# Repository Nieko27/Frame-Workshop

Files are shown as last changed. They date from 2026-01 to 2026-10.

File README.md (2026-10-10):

## Note
A forewarning, I am very new to electronics design in general. I apologize in advance for any really baffling design decisions. I hope to learn from these projects and will keep them updated as I learn more. Thank you for your patience.

> ⚠️This is an unofficial 3rd-party project with no association to Valve.
<p align="center">
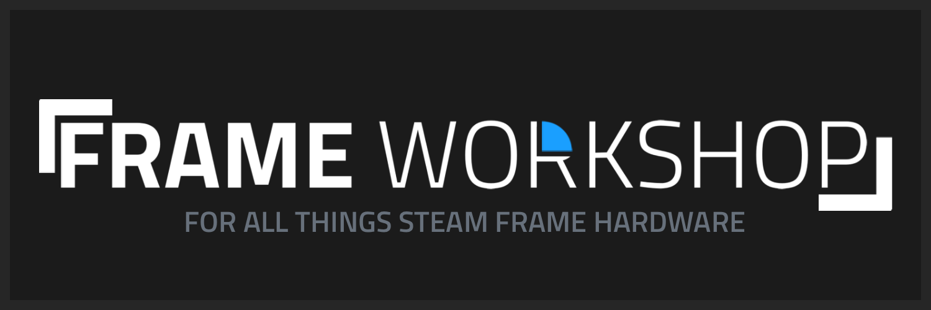
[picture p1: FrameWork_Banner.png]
Banner
  
</p>

## Offical CAD and Electronic files from Valve
If you are looking for Valves offical CAD and electronic information for the Frame it can be found here;
https://gitlab.steamos.cloud/SteamHardware/SteamFrame/-/tree/master

# What is Frame Workshop?
Frame Workshop is intended to be an open-source bundle of different hardware peripherals built around (but not always exclusive to) the Steam Frame. The idea is to leverage the Steam Frames' modularity and general openness to create a collection of open-source hardware projects that the community can provide feedback on, expand upon, or even take and turn into something entirely new, creating a feedback loop that adds to an ever-expanding ecosystem for the Steam Frame. All source files, from schematics to STLs, will be included, allowing every aspect of each project to be modified and produced to anyone’s preferences. 

## Hardware
Below is a list of all currently in development hardware projects, including a brief overview and notes on changes made to the most recent revision.

### Frame Facetracker
The Frame face tracker is pretty self-explanatory: it is a module that uses a camera for face tracking in social experiences like VRChat. There are 2 versions planned: one built with the steam frame in mind, using its expansion ports, and another that plugs into the back USB port of the frame and uses an ESP32 to run the camera.

<p align="left">
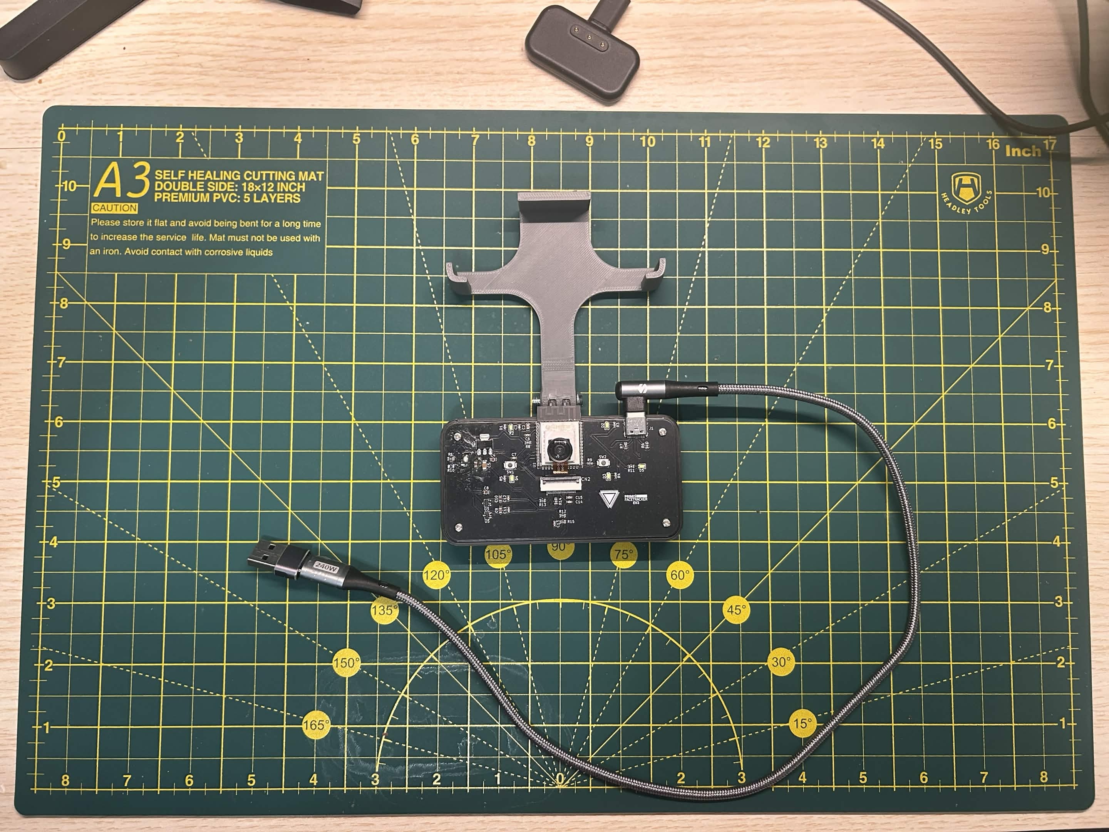
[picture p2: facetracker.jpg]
  
</p>

>Headset-Agnostic Version EV2

<br>
Link to the facetracker files:
https://github.com/Nieko27/FrameWork/tree/main/KICAD%20Projects/Primis_FaceTracker

### Versipellis (General Purpose Dongle)
Versipellis is a dongle utilising an nRF52833 intended as a general-purpose dongle for communicating with any Frame-based hardware, whether it be controllers or trackers. It will be programmable by the end user for whatever they intend to use it for. There will be two versions: one utilising no parts smaller than a 0603 package, making it easy to hand-assemble, and another using much smaller parts that, while smaller, will require assembly by a service like JLCPCB.

<p align="left">
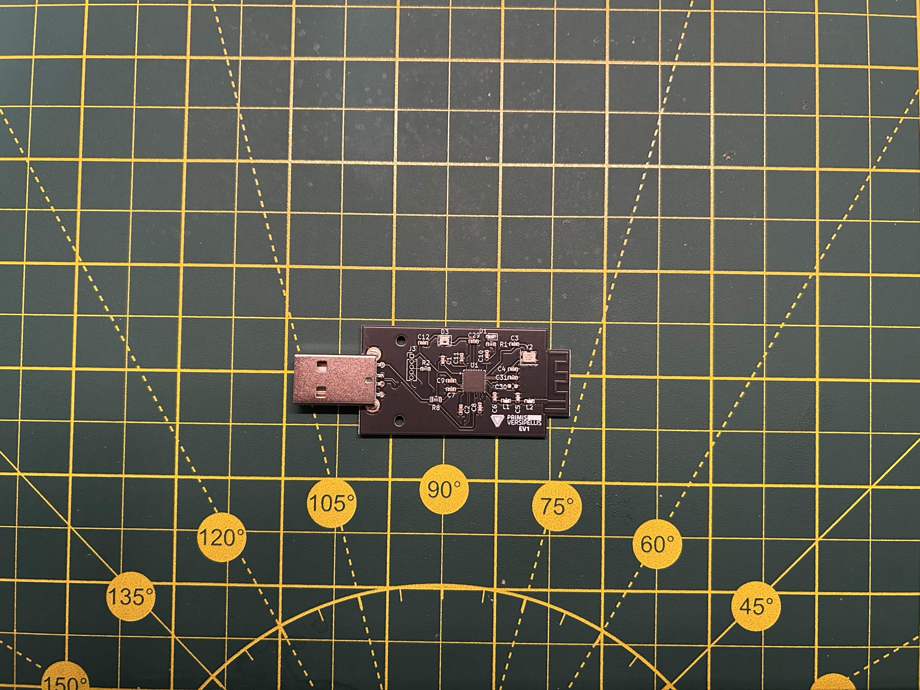
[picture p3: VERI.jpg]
  
</p>

>Hand-assemblable EV1

<br>
Link to Versipellis' files:
https://github.com/Nieko27/FrameWork/tree/main/KICAD%20Projects/Primis_Versipellis
<br>
Link to VeriMini files:
https://github.com/Nieko27/FrameWork/tree/main/KICAD%20Projects/Primis_Versipellis

### Locus (Tracker)
Locus is intended to be a tracker like Vive or Tundra, but without reliance on lighthouse base stations. Since the Steam Frame isn’t limited to base station vision, trackers being used with it shouldn’t be either. Similar to Versipellis, Locus will also use an nRF52833 along with an LSM6DSV16X IMU. The idea is that it will track similarly to a slime tracker, but also use the Steam Frame’s optical tracking to address the drift problem of EMF trackers. 

<p align="left">
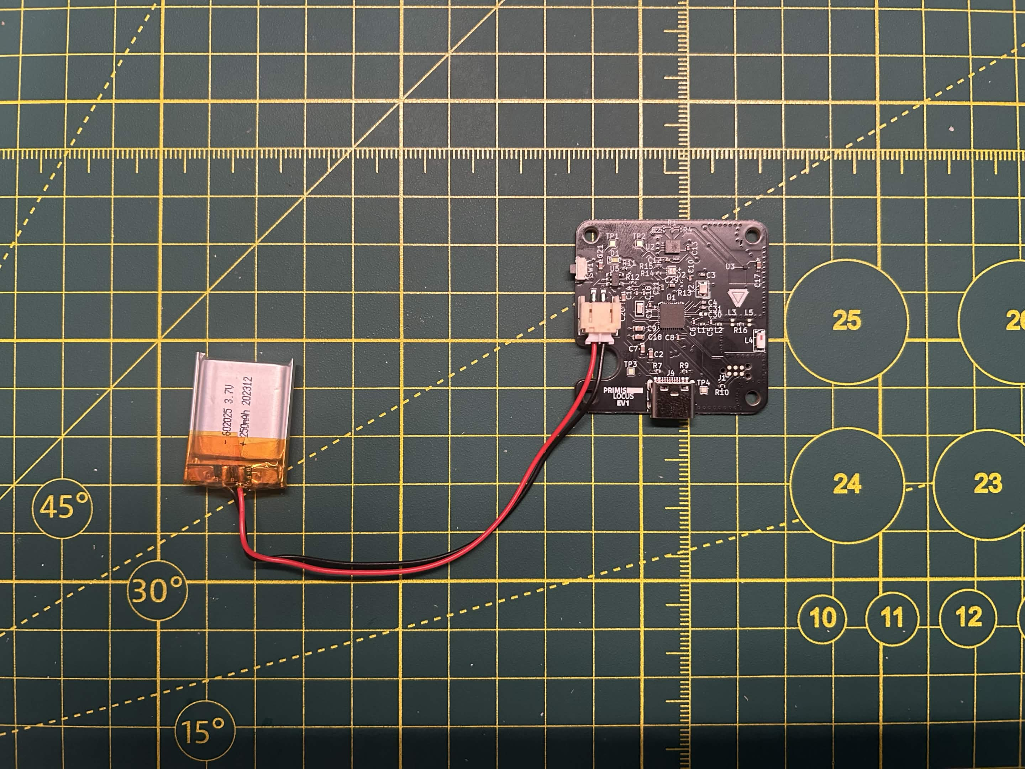
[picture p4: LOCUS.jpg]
  
</p>

Link to Locus' files:
https://github.com/Nieko27/FrameWork/tree/main/KICAD%20Projects/Primis_Locus

### Future Projects
* USB Hub
* Index speaker mod kit

## Project Goals

* Keep costs to the users as low as possible. You've already spent over a $1000 on the headset itself, so it would be nice not to have to spend another $1000 customizing it to your liking. How this would be achieved is by everything being open and nothing being sold, for example I’m working on a face tracker that takes advantage of the PCIe port on the Frame, the idea is when its done instead of me having to handle production, shipping and all the joys of selling a project I give the source files out with a tutorial on how to order it yourself from a company like JLCPCB. Now, obviously, this still won't be free to the end user, but it will be much cheaper than if I were to sell it. For example, I have made the first prototype of the face-tracker, and in small quantities (5 to be exact), it cost me $25 per board. Compare that to something like the old Vive face trackers, which I think were closer to $100, and you save a nice bit of money. 

* Give the end user total control over the hardware. Don't like how I've done something? Fire up Blender or KiCad and change it yourself to fit whatever need you have in mind. I know not everyone will be able to do this, as it requires familiarity with the software, but it gives people the ability to do so. Obviously, with this in mind, I want to make the experience for everyone as smooth as possible out of the box, so I will be listening to feedback as much as possible to achieve that. 

* Create a feedback loop. I have all this under a CERN-OHL-S-2.0 license, which (as far as I understand) means you can do anything you want with anything in the repo, including selling it for profit, but you must open-source anything you do under the same license. This way it keeps everything open to the community, and every addition helps grow the ecosystem around the Steam Frame. 

## Ideas
A few ideas for possible mods for the Frame have already been thrown around. If you have an idea for a mod, whether it's a full module or as simple as a 3D-printable counterweight, feel free to open a pull request under the enhancement tag. You may also feel free to email me at nieko972@gmail.com.

### Find me on
* Twitter; https://x.com/Merlinr271
* Bluesky; https://bsky.app/profile/merlin271.bsky.social

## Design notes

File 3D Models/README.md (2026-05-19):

Parts for the PCBs that can be 3D printed

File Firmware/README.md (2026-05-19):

## Note
This folder will hold the firmware for each device and a guide on how to set it up.

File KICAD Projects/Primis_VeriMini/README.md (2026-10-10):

### WARNING
This has yet to be produced by me yet, I have not yet added the gerber files to this repo yet as I have no idea if it will work yet, order them at your own risk.
# VERI-MINI
The general purpose dongle for the Steam Frame but smaller.
<p align="left">
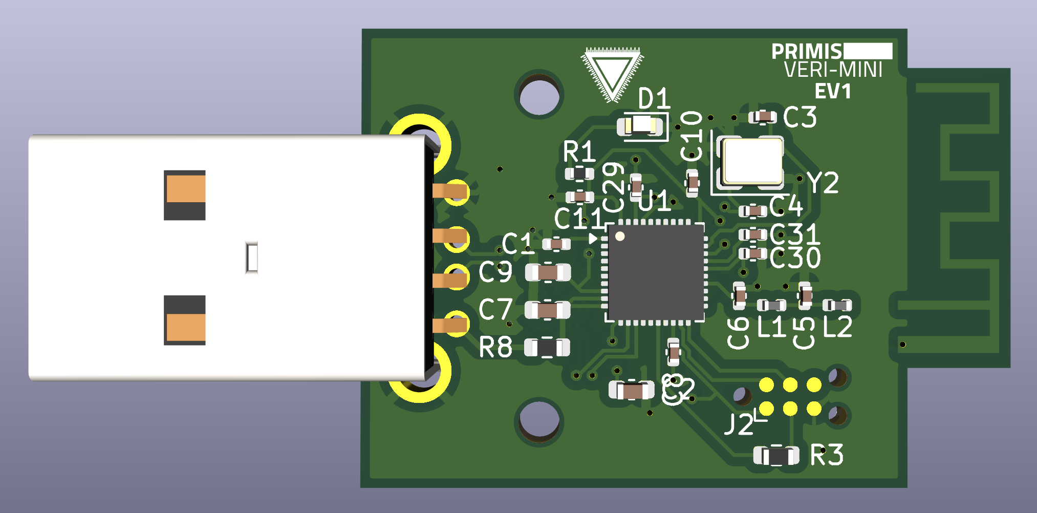
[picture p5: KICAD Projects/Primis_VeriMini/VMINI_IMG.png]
  
</p>

### Schematics
<p align="left">
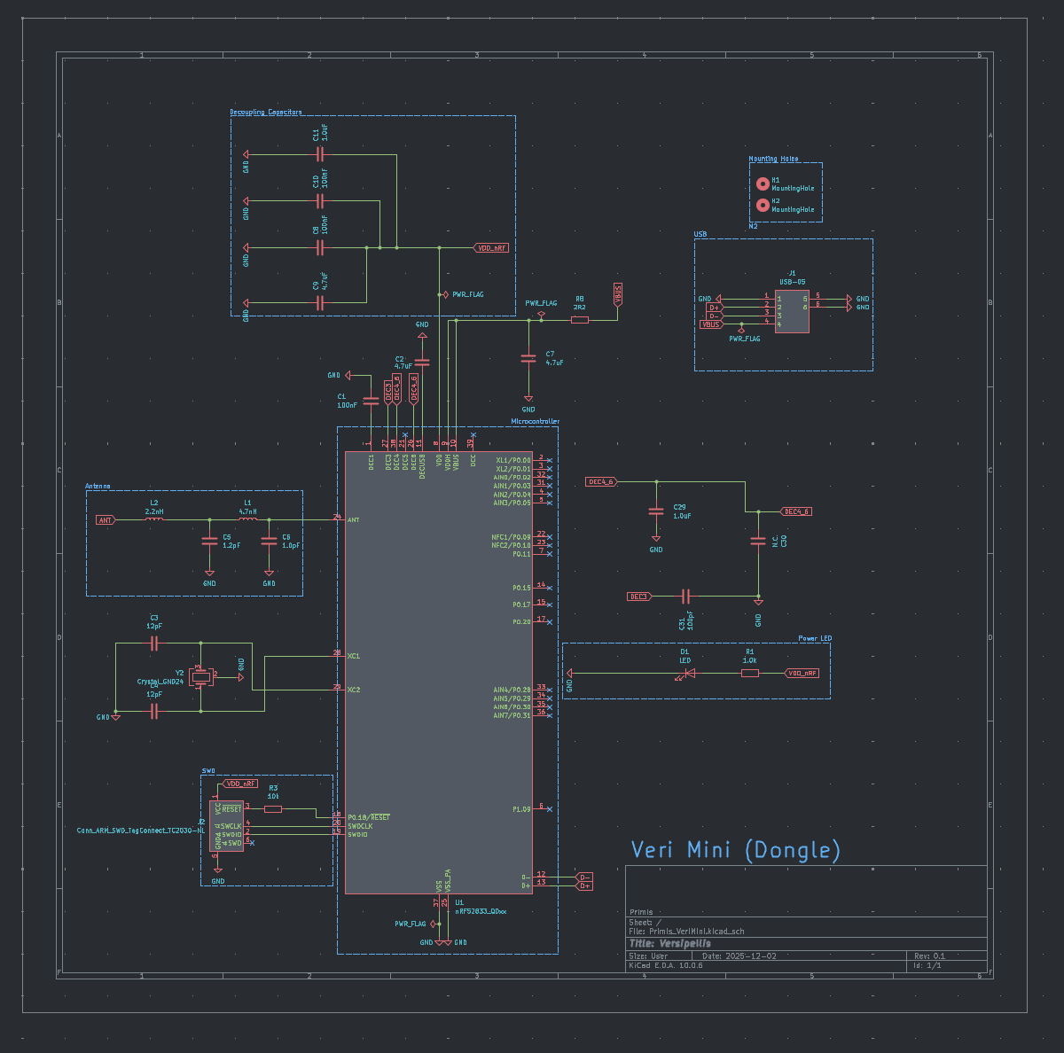
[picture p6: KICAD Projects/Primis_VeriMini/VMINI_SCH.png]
  
</p>

### PCB
<p align="left">
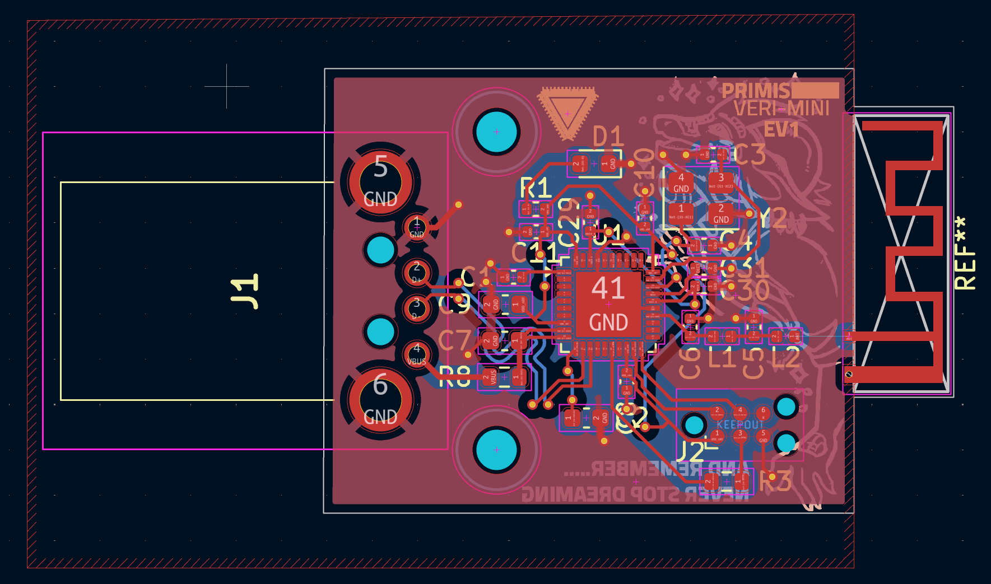
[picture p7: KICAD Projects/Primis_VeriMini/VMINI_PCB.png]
  
</p>

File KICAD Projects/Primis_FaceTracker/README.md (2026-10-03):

### WARNING
This has yet to be produced by me yet, I have not yet added the gerber files to this repo yet as I have no idea if it will work yet, order them at your own risk.
### TODO
* Copper pads under power supply
* Clean up and condense
* ESD Protection
# Face Tracker (Headset-Agnostic Version)
Headset-agnostic face tracker. Can be used with Frame by using the USB-C port on the battery.
## Current Isseus
Q1 is setup improperly, removing it and R10 as well as bridging the now empty pads solves the issue. Will fix in EV3 along with some changes to layout and LEDs.
<p align="left">
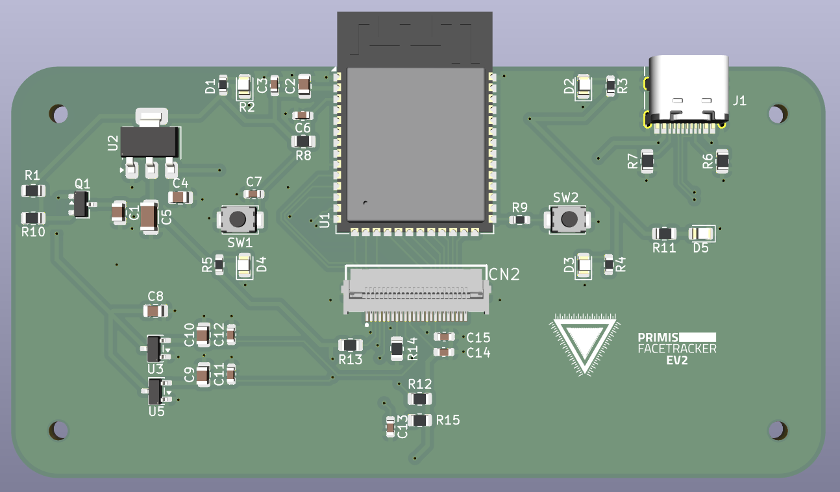
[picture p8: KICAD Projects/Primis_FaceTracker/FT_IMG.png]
  
</p>

### Schematics
<p align="left">
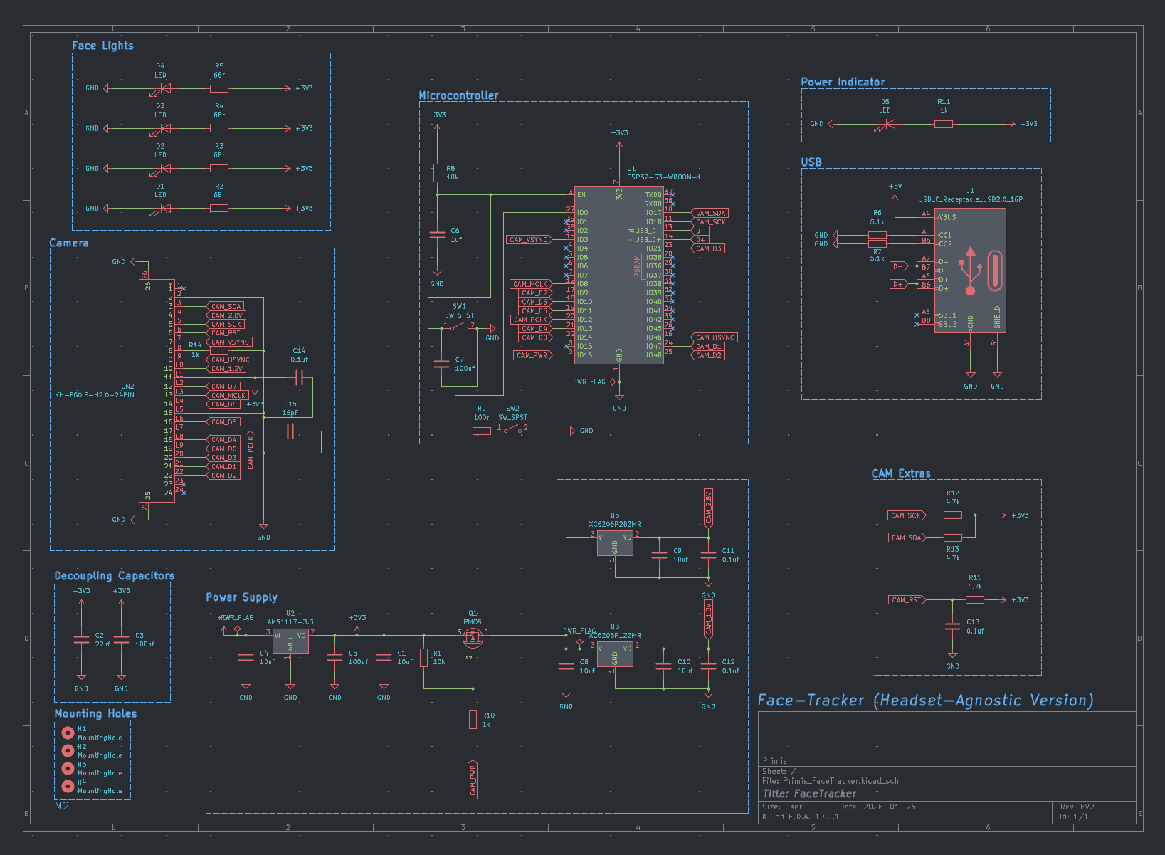
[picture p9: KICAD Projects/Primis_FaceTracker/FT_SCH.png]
  
</p>

### PCB
<p align="left">
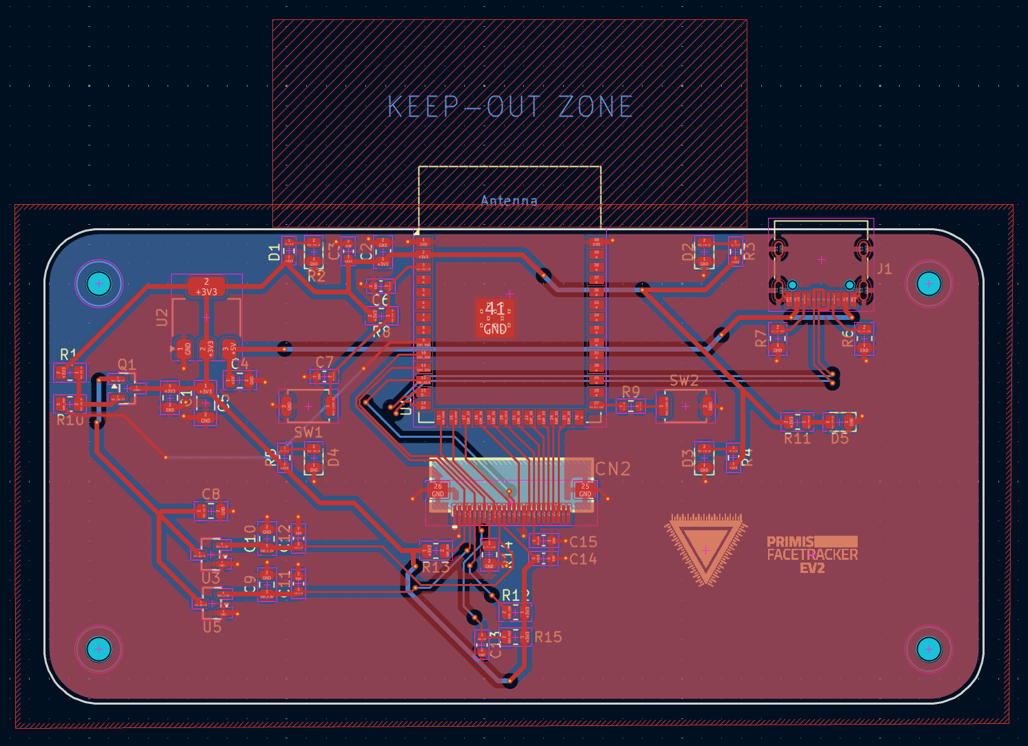
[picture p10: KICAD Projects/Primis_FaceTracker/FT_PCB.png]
  
</p>

### EV2
<p align="left">
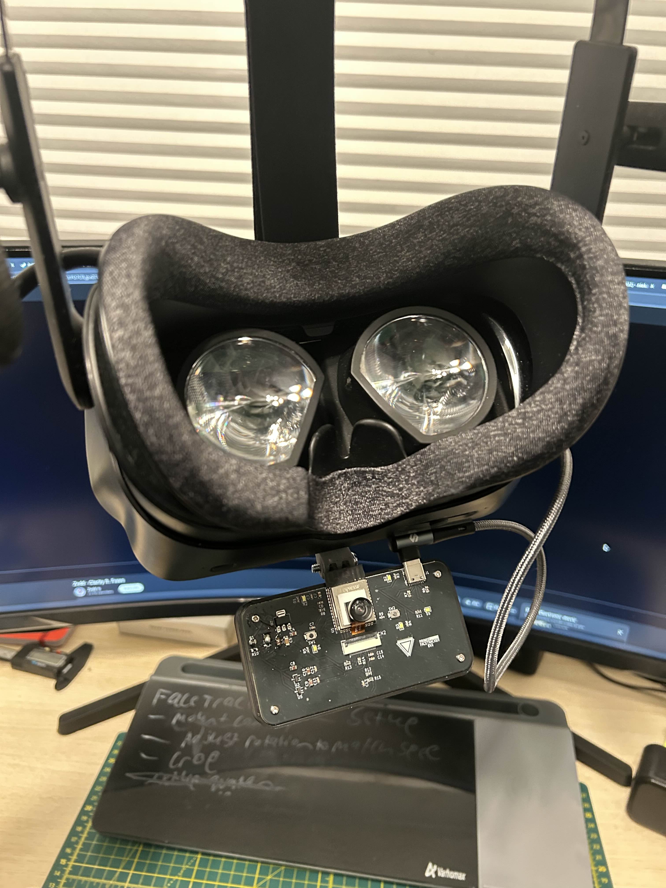
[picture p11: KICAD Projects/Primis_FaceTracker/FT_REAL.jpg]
  
</p>

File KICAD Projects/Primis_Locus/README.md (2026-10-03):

# Locus
Tracker for the Steam Frame.
## Current Isseus
Currently the SDA line is getting pulled 0.02v while running the slime firmware, if I halt the NRF52833 it jumps up to the expected 1.8v. Currently working on figuring out why this happens.
<p align="left">
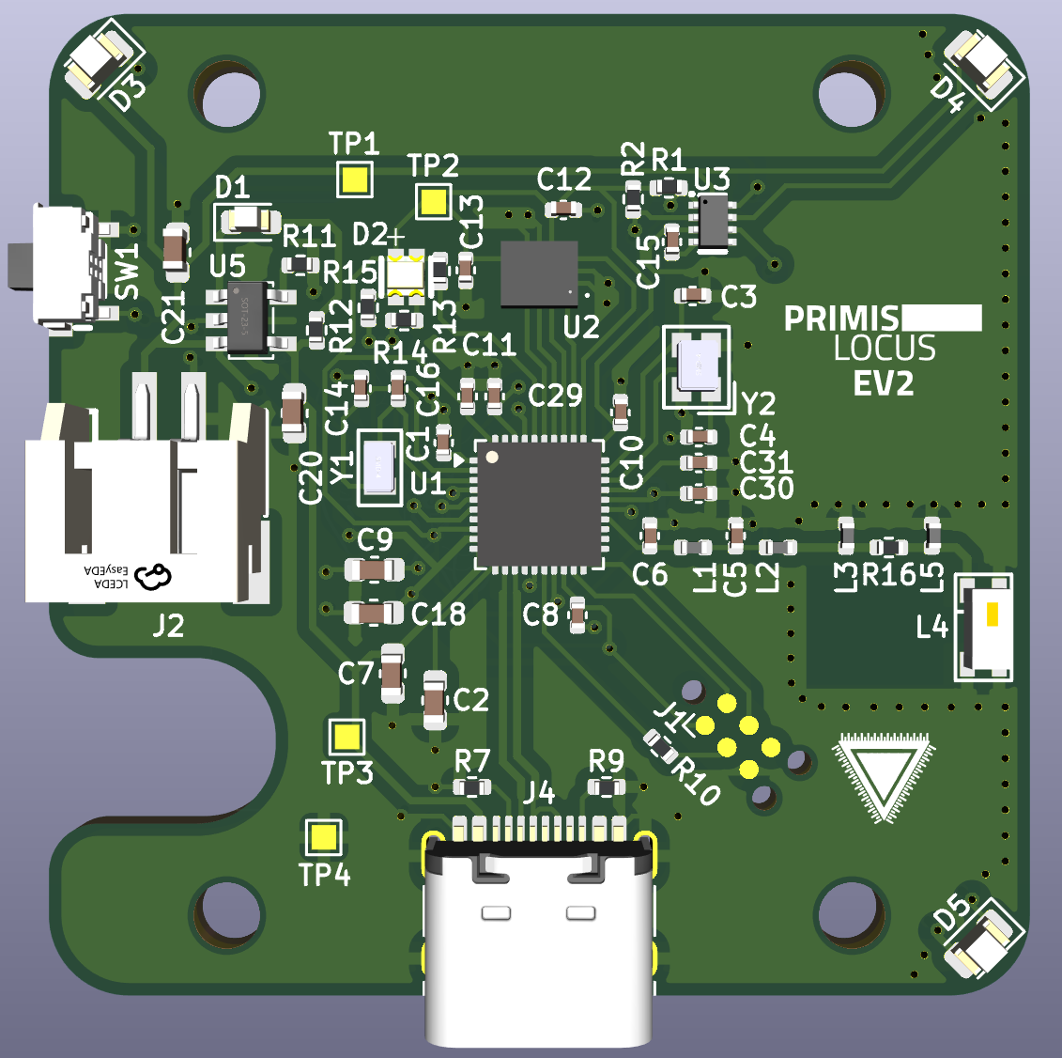
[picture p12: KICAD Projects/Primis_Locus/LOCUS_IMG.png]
  
</p>

### Schematics
<p align="left">
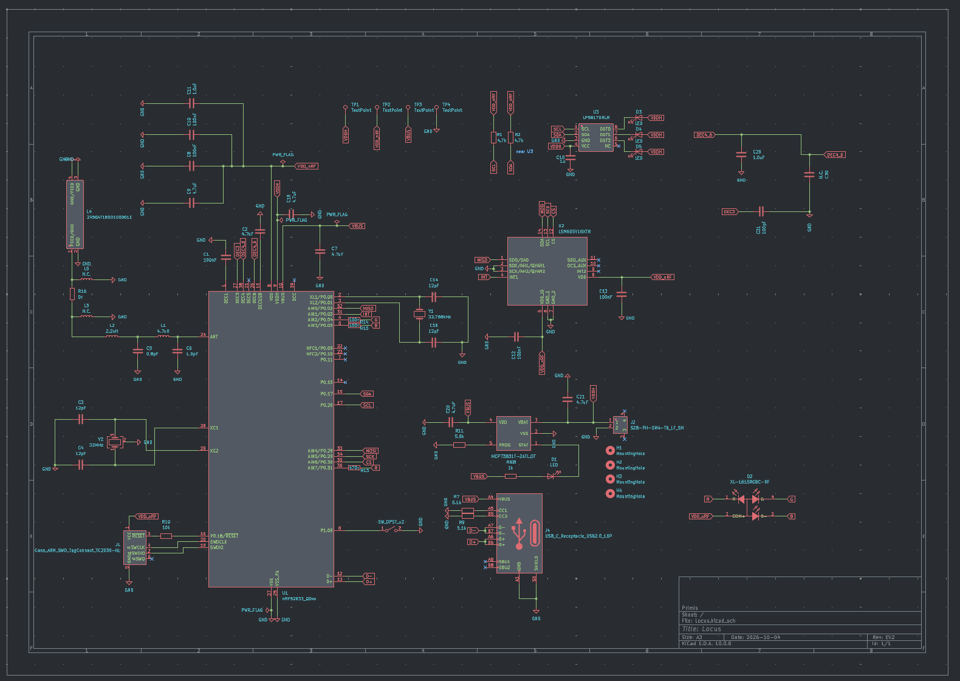
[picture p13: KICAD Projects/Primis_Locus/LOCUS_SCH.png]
  
</p>

### PCB
<p align="left">
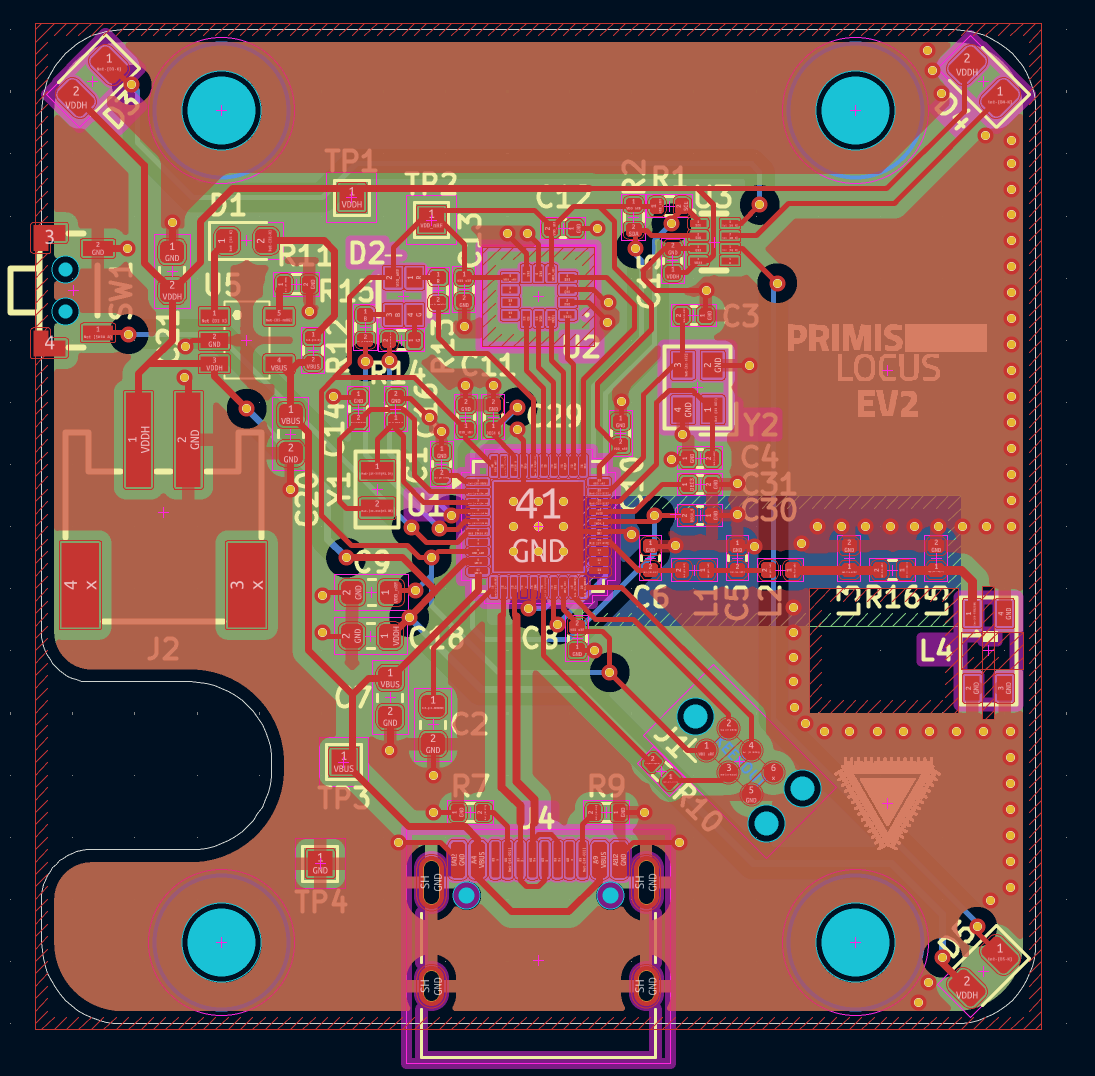
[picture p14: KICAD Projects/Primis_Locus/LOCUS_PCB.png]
  
</p>

### EV1
<p align="left">
  Banner
</p>

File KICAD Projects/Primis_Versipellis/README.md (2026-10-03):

### WARNING
This has yet to be produced by me yet, I have not yet added the gerber files to this repo yet as I have no idea if it will work yet, order them at your own risk.
# Versipellis
The general purpose dongle for the Steam Frame.
## Current Issues
The current version works but I made some mistakes on the clock speeds for the chip. This doesnt seem to effect perforamnce of chip any but Im not sure how it would affect the life time of the chip. Will fix in a future version.
<p align="left">
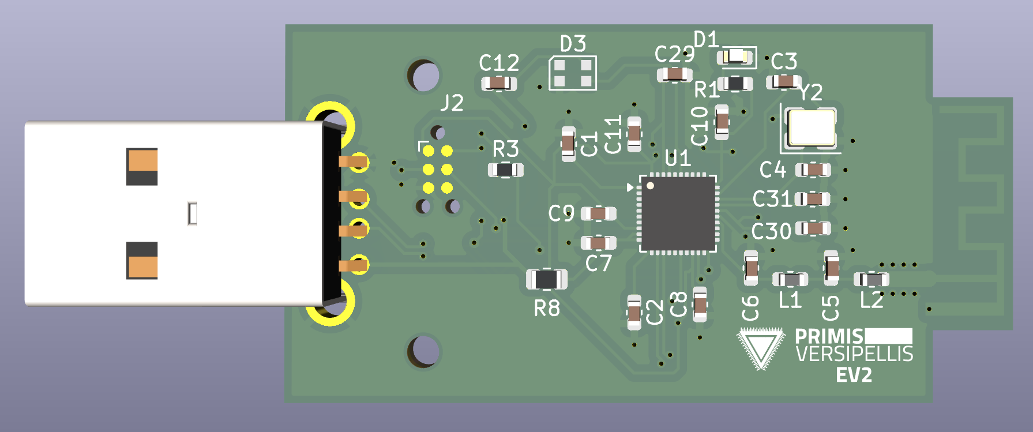
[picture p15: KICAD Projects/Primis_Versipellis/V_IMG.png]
  
</p>

### Schematics
<p align="left">
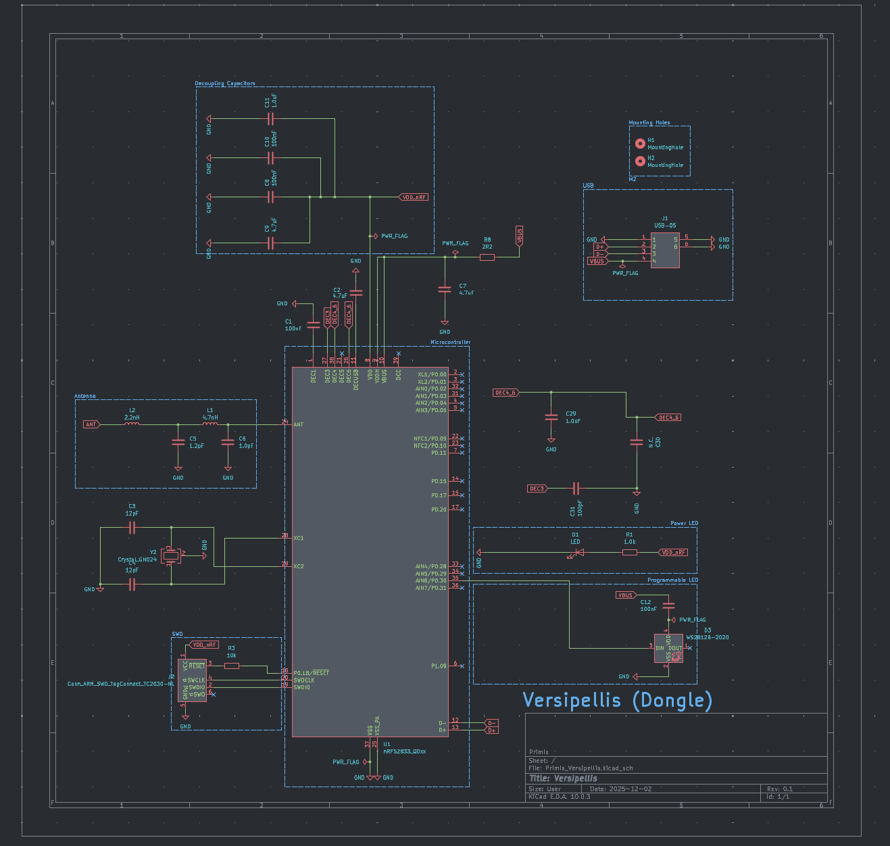
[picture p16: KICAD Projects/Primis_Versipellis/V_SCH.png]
  
</p>

### PCB
<p align="left">
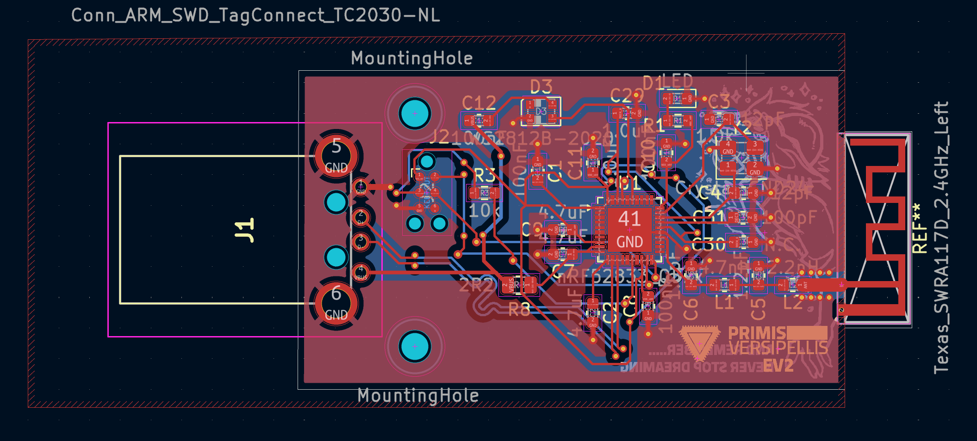
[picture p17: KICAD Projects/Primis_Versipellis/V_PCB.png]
  
</p>

### EV1
<p align="left">
  Banner
</p>

### EV2
<p align="left">
  Banner
</p>

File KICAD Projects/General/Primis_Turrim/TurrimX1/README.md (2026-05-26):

### WARNING
This has yet to be produced by me yet, I have not yet added the gerber files to this repo yet as I have no idea if it will work yet, order them at your own risk.
# Dongle Dock (1-Port)
Headset-agnostic face tracker. Can be used with Frame by using the USB-C port on the battery.
<p align="left">
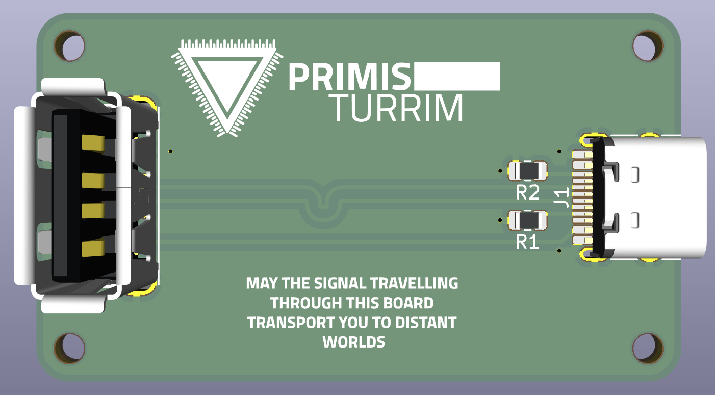
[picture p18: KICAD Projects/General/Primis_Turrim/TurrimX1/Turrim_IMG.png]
  
</p>

### Schematics
<p align="left">
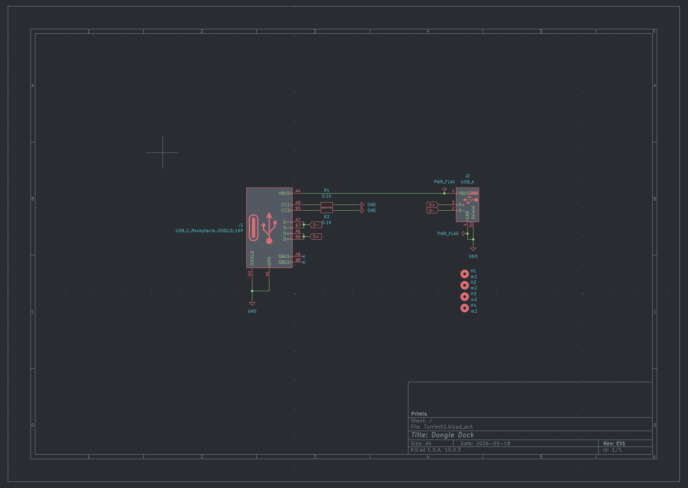
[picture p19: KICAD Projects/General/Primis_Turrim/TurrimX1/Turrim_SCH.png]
  
</p>

### PCB
<p align="left">
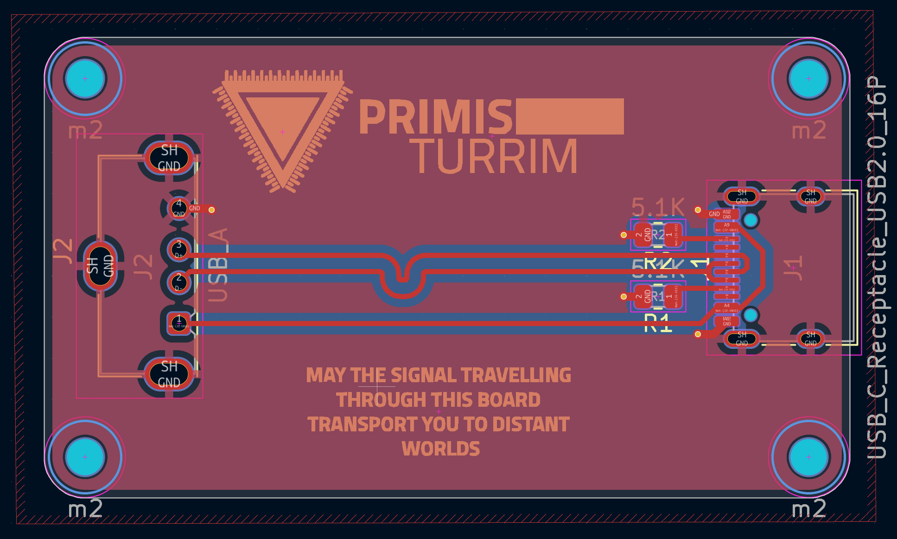
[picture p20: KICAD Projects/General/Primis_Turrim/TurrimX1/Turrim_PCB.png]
  
</p>

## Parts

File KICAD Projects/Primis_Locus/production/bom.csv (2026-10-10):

Designator | Footprint | Quantity | Value | LCSC Part #
C1, C10, C12, C13, C8 | 0402 | 5 | 100nF
C11, C29 | 0402 | 2 | 1.0uF
C14, C16, C3, C4 | 0402 | 4 | 12pF
C15 | 0402 | 1 | 1u
C18, C2, C20, C21, C7, C9 | 0603 | 6 | 4.7uF
C30, L3, L5 | 0402 | 3 | N.C.
C31 | 0402 | 1 | 100pF
C5 | 0402 | 1 | 0.8pF
C6 | 0402 | 1 | 1.0pF
D1 | 0603 | 1 | LED
D2 | XL-1615RGBC-RF | 1 | XL-1615RGBC-RF | C965840
D3, D4, D5 | 0805 | 3 | LED
J2 | S2B-PH-SM4-TB_LF_SN | 1 | S2B-PH-SM4-TB_LF_SN | C295747
J4 | USB_C_Receptacle_HRO_TYPE-C-31-M-12 | 1 | USB_C_Receptacle_USB2.0_16P
L1 | 0402 | 1 | 4.7nH
L2 | 0402 | 1 | 2.2nH
L4 | 2450AT18D0100001E | 1 | 2450AT18D0100001E | C7450310
R1, R2 | 0402 | 2 | 4.7k
R10 | 0402 | 1 | 10k
R11 | 0402 | 1 | 5.6k
R12 | 0402 | 1 | 1k
R13 | 0402 | 1 | 470r
R14, R15 | 0402 | 2 | 100r
R16 | 0402 | 1 | 0r
R7, R9 | 0402 | 2 | 5.1k
SW1 | SH-1806SA-A3DW-04 | 1 | SW_DPST_x2
TP1, TP2, TP3, TP4 | TestPoint_Pad_1.0x1.0mm | 4 | TestPoint
U1 | QFN-40-1EP_5x5mm_P0.4mm_EP3.6x3.6mm | 1 | nRF52833_QDxx
U2 | LSM6DSV16BXTR | 1 | LSM6DSV16XTR
U3 | LP5817DRLR | 1 | LP5817DRLR | C47262829
U5 | MCP73831T-2ATI_OT | 1 | MCP73831T-2ATI_OT | C14879
Y1 | SC-20S32_768kHz20PPM9pF | 1 | 32.768kHz
Y2 | NX2016SA-32MHZ-STD-CZS-5 | 1 | 32MHz

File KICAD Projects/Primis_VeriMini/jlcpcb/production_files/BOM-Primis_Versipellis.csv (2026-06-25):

Comment | Designator | Footprint | LCSC | Quantity
1.2pF | C5 | C_0603_1608Metric |  | 1
2R2 | R8 | R_0805_2012Metric |  | 1
1.0pF | C6 | C_0603_1608Metric |  | 1
12pF | C4 | C_0603_1608Metric |  | 1
4.7uF | C2 | C_0603_1608Metric |  | 1
USB-05 | J1 | USB05 |  | 1
WS2812B-2020 | D3 | LED_WS2812B-2020_PLCC4_2.0x2.0mm |  | 1
4.7uF | C9 | C_0603_1608Metric |  | 1
nRF52833_QDxx | U1 | QFN-40-1EP_5x5mm_P0.4mm_EP3.6x3.6mm |  | 1
100nF | C8 | C_0603_1608Metric |  | 1
12pF | C3 | C_0603_1608Metric |  | 1
100pF | C31 | C_0603_1608Metric |  | 1
1.0k | R1 | R_0603_1608Metric |  | 1
4.7uF | C7 | C_0603_1608Metric |  | 1
LED | D1 | LED_0603_1608Metric |  | 1
N.C. | C30 | C_0603_1608Metric |  | 1
1.0uF | C29 | C_0603_1608Metric |  | 1
1.0uF | C11 | C_0603_1608Metric |  | 1
Crystal_GND24 | Y2 | Crystal_SMD_Abracon_ABM8G-4Pin_3.2x2.5mm |  | 1
100nF | C10 | C_0603_1608Metric |  | 1
2.2nH | L2 | L_0603_1608Metric |  | 1
10k | R3 | R_0603_1608Metric |  | 1
4.7nH | L1 | L_0603_1608Metric |  | 1
100nF | C1 | C_0603_1608Metric |  | 1
100nF | C12 | C_0603_1608Metric |  | 1

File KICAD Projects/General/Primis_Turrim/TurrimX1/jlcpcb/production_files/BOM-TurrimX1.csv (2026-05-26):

Comment | Designator | Footprint | LCSC | Quantity
5.1K | R2 | R_0805_2012Metric |  | 1
5.1K | R1 | R_0805_2012Metric |  | 1
USB_A | J2 | USB_A_Molex_105057_Vertical |  | 1
USB_C_Receptacle_USB2.0_16P | J1 | USB_C_Receptacle_HRO_TYPE-C-31-M-12 |  | 1

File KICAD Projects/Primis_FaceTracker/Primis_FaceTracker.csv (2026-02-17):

Source: | /home/cody/Documents/GitHub/FrameWork/KICAD Projects/Primis_FaceTracker/Primis_FaceTracker.kicad_sch
Date: | 2026-02-16T21:55:50-0500
Tool: | Eeschema 9.0.7
Generator: | /usr/share/kicad/plugins/bom_csv_grouped_by_value_with_fp.py
Component Count: | 44
Ref | Qnty | Value | Cmp name | Footprint | Description | Vendor | DNP
C1, C4, C8, C9, C10 | 5 | 10uf | C | Capacitor_SMD:C_0805_2012Metric | Unpolarized capacitor
C2 | 1 | 22uf | C | Capacitor_SMD:C_0805_2012Metric | Unpolarized capacitor
C3, C7 | 2 | 100nf | C | Capacitor_SMD:C_0603_1608Metric | Unpolarized capacitor
C5 | 1 | 100uf | C | Capacitor_SMD:C_1206_3216Metric | Unpolarized capacitor
C6 | 1 | 1uf | C | Capacitor_SMD:C_0603_1608Metric | Unpolarized capacitor
C11, C12, C13, C14 | 4 | 0.1uf | C | Capacitor_SMD:C_0603_1608Metric | Unpolarized capacitor
C15 | 1 | 15pF | C | Capacitor_SMD:C_0603_1608Metric | Unpolarized capacitor
CN2 | 1 | KH-FG0.5-H2.0-24PIN | KH-FG0.5-H2.0-24PIN | FaceTracker:FPC-SMD_KH-FG0.5-H2.0-24PIN
D1, D2, D3, D4, D5 | 5 | LED | LED | LED_SMD:LED_0805_2012Metric | Light emitting diode
J1 | 1 | USB_C_Receptacle_USB2.0_16P | USB_C_Receptacle_USB2.0_16P | Connector_USB:USB_C_Receptacle_HRO_TYPE-C-31-M-12 | USB 2.0-only 16P Type-C Receptacle connector
Q1 | 1 | PMOS | PMOS | Package_TO_SOT_SMD:SOT-23 | P-MOSFET transistor, drain/source/gate
R1, R8 | 2 | 10k | R | Resistor_SMD:R_0805_2012Metric | Resistor
R2, R3, R4, R5 | 4 | 68r | R | Resistor_SMD:R_0603_1608Metric | Resistor
R6, R7 | 2 | 5.1k | R | Resistor_SMD:R_0805_2012Metric | Resistor
R9 | 1 | 100r | R | Resistor_SMD:R_0603_1608Metric | Resistor
R10, R11, R14 | 3 | 1k | R | Resistor_SMD:R_0805_2012Metric | Resistor
R12, R13, R15 | 3 | 4.7k | R | Resistor_SMD:R_0805_2012Metric | Resistor
SW1, SW2 | 2 | SW_SPST | SW_SPST | Button_Switch_SMD:SW_SPST_TS-1088-xR020 | Single Pole Single Throw (SPST) switch
U1 | 1 | ESP32-S3-WROOM-1 | ESP32-S3-WROOM-1 | RF_Module:ESP32-S3-WROOM-1 | RF Module, ESP32-S3 SoC, Wi-Fi 802.11b/g/n, Bluetooth, BLE, 32-bit, 3.3V, onboard antenna, SMD
U2 | 1 | AMS1117-3.3 | AMS1117-3.3 | Package_TO_SOT_SMD:SOT-223-3_TabPin2 | 1A Low Dropout regulator, positive, 3.3V fixed output, SOT-223
U3 | 1 | XC6206P122MR | XC6206PxxxMR | Package_TO_SOT_SMD:SOT-23-3 | Positive 60-250mA Low Dropout Regulator, Fixed Output, SOT-23
U5 | 1 | XC6206P282MR | XC6206PxxxMR | Package_TO_SOT_SMD:SOT-23-3 | Positive 60-250mA Low Dropout Regulator, Fixed Output, SOT-23

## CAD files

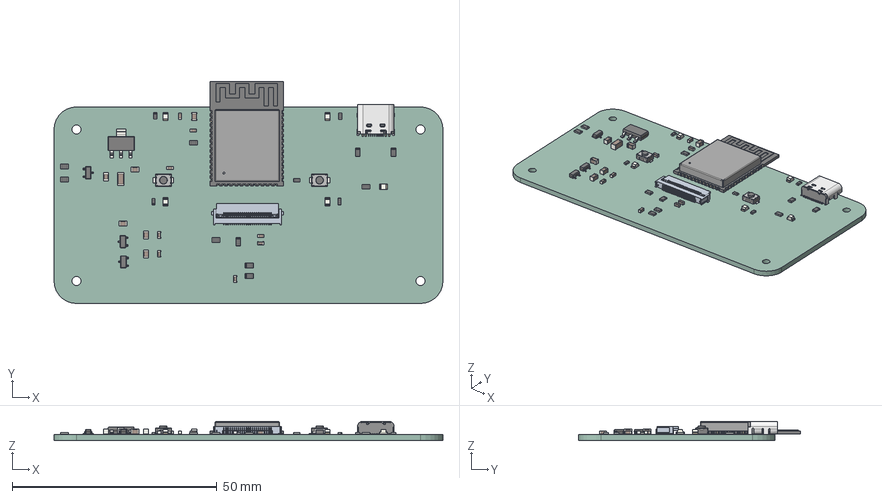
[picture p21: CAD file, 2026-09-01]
3D Models/FaceTracker/STEP/FaceTrackerA.step
95.0 x 54.2 x 4.75 mm
R_0805_2012Metric x 10
ConPins
PcbPins
Mold
Frame
C_0603_1608Metric x 8
C_1206_3216Metric
LED_0805_2012Metric x 5
C_0805_2012Metric x 6
SOT-223
R_0603_1608Metric x 5
SOT-23-3 x 2
SW_SPST_TS-1088-xR020 x 2
ESP32-S3-WROOM-1
SOT-23
Primis_FaceTracker_PCB

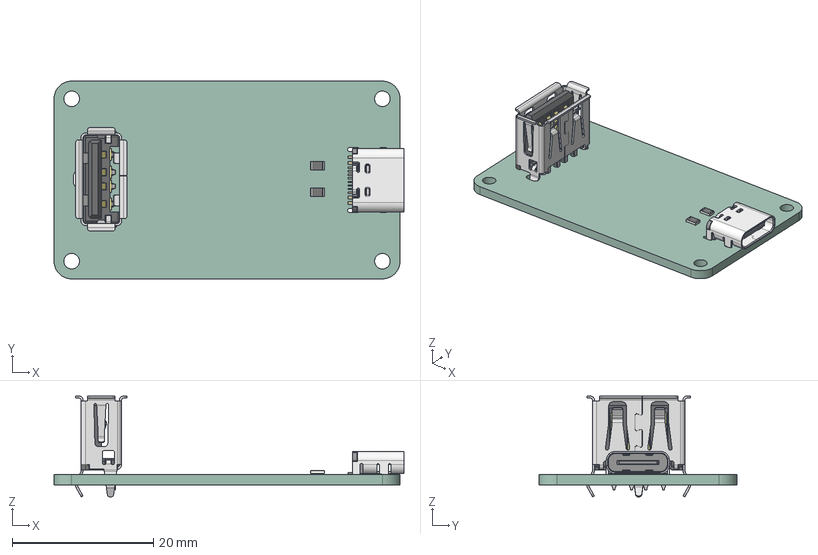
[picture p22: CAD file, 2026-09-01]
3D Models/General/TurrimX1/STEP/Turrim.step
49.6 x 28.0 x 14.3 mm
R_0805_2012Metric x 2
ConPins
PcbPins
Mold
Frame
TurrimX1_PCB

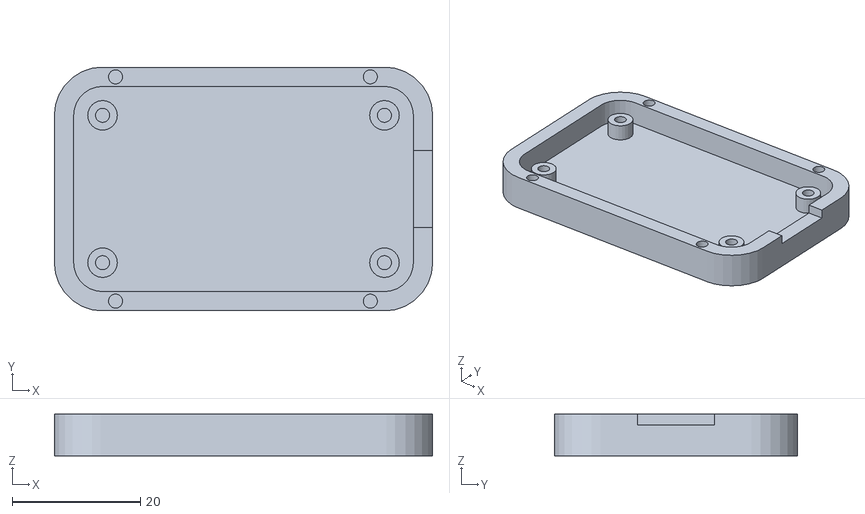
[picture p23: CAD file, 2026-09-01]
3D Models/General/TurrimX1/Turrimlower_fixed.stl
59.0 x 38.0 x 6.51

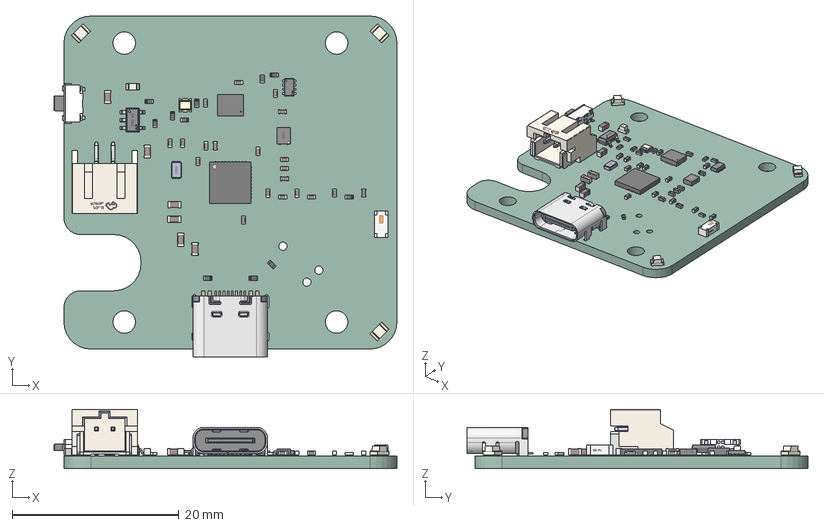
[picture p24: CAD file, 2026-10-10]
3D Models/Locus/STEP/LocusEV2.step
41.2 x 41.0 x 7.10 mm
L_0402_1005Metric x 4
QFN-40-1EP_5x5mm_Pitch0.4mm
R_0402_1005Metric x 11
C_0603_1608Metric x 6
LED_0805_2012Metric x 3
C_0402_1005Metric x 16
SOT-583-8_L2.1-W1.6-P0.50-LS1.6-BL
LED-ARRAY-SMD_4P-L1.6-W1.5-BL
OSC-SMD_4P-L2.0-W1.6-H0.8
OSC-SMD_L2.0-W1.2-H0.5
SW-SMD_SH-1806SA-A3DW-04-1
ConPins
PcbPins
Mold
Frame
SOT-23-5_L2.9-W1.6-H1.1-LS2.8-P0.95
LED_0603_1608Metric
CONN-SMD_P2.00_S2B-PH-SM4-TB-LF-SN
ANT-SMD_4P-L3.2-W1.6-H1.2
Locus-unsaved-export-1Y5H8w_PCB

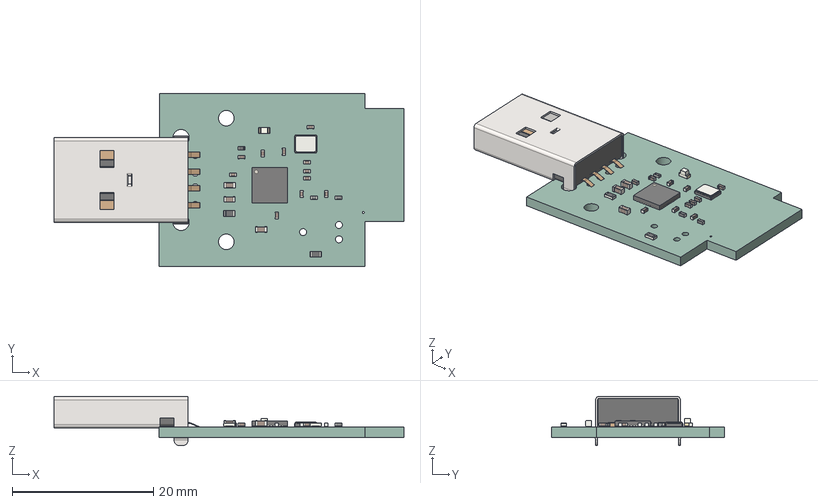
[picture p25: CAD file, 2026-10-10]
3D Models/VeriMini/STEP/Primis_VeriMini.step
49.6 x 24.5 x 7.00 mm
C_0402_1005Metric x 11
R_0603_1608Metric x 2
C_0603_1608Metric x 3
USB Connector Type A male, SMT
QFN-40-1EP_5x5mm_Pitch0.4mm
R_0402_1005Metric
LED_0603_1608Metric
Crystal_SMD_Abracon_ABM8G-4Pin_3.2x2.5mm
L_0402_1005Metric x 2
Primis_VeriMini-unsaved-export-hdQRqW_PCB

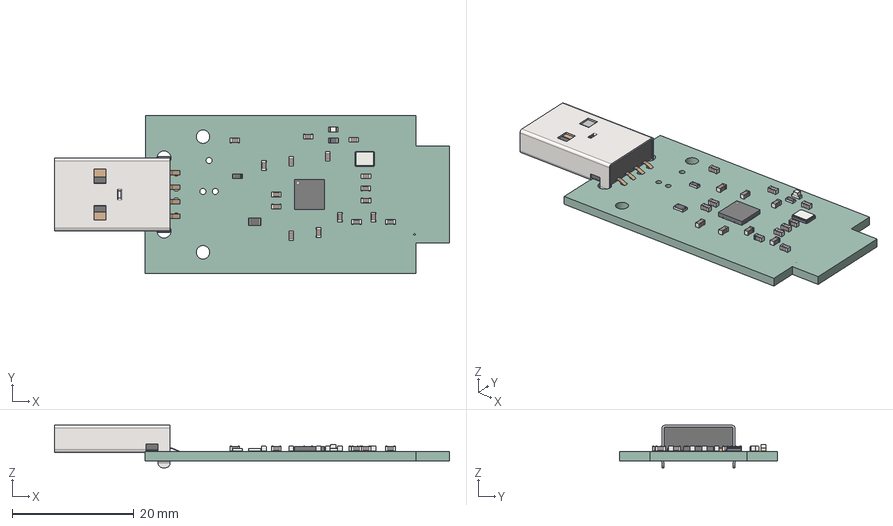
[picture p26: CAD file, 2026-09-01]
3D Models/Versipellis/STEP/VeriEV2.step
64.9 x 26.0 x 7.00 mm
C_0603_1608Metric x 15
R_0805_2012Metric
USB Connector Type A male, SMT
QFN-40-1EP_5x5mm_Pitch0.4mm
R_0603_1608Metric x 2
LED_0603_1608Metric
Crystal_SMD_Abracon_ABM8G-4Pin_3.2x2.5mm
L_0603_1608Metric x 2
Primis_Versipellis_PCB

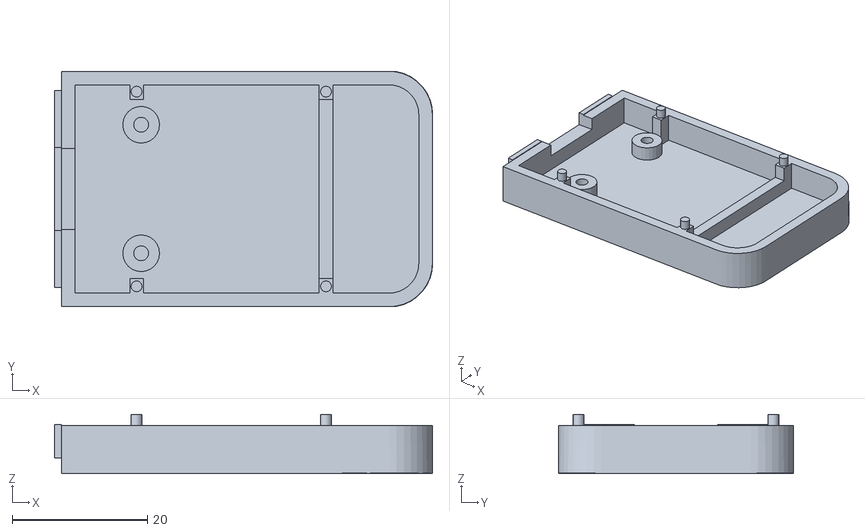
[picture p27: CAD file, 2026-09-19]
3D Models/Versipellis/Veri_Bot.stl
55.9 x 34.8 x 8.73

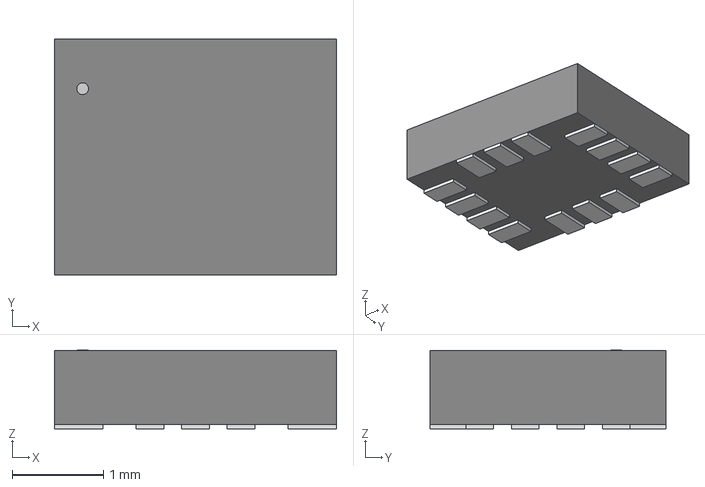
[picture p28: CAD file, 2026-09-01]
KICAD Projects/_Shared/Models/LGA-14L_STM.step
3.10 x 2.59 x 0.866 mm

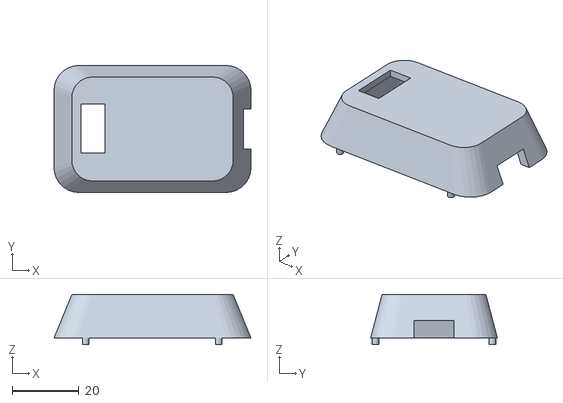
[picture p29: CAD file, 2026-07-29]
3D Models/General/TurrimX1/Turrimupper.stl
59.0 x 38.0 x 15.1

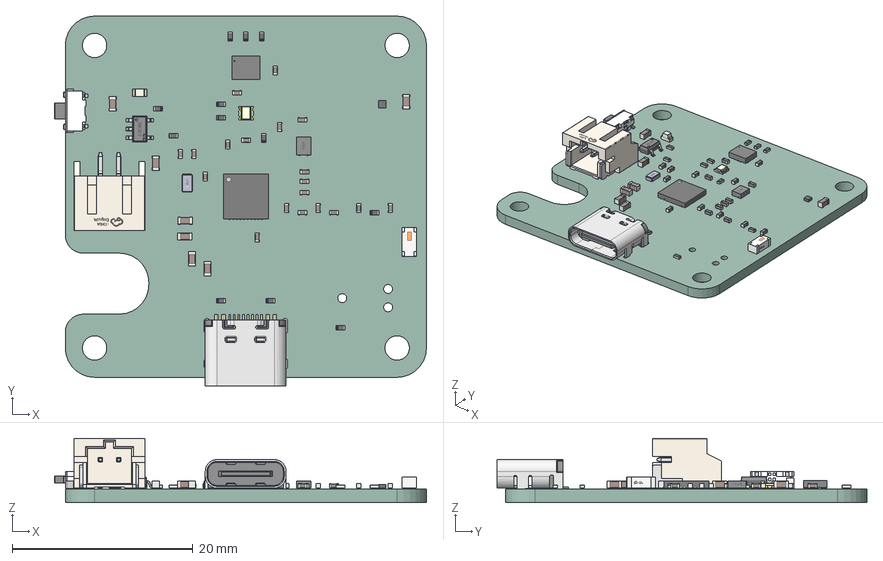
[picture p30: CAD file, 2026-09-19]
3D Models/Locus/STEP/Locus.step
41.2 x 41.0 x 7.10 mm
R_0402_1005Metric x 12
L_0402_1005Metric x 4
QFN-40-1EP_5x5mm_Pitch0.4mm
C_0603_1608Metric x 7
C_0402_1005Metric x 15
(Unsaved)
LED-ARRAY-SMD_4P-L1.6-W1.5-BL
OSC-SMD_4P-L2.0-W1.6-H0.8
OSC-SMD_L2.0-W1.2-H0.5
SW-SMD_SH-1806SA-A3DW-04-1
ConPins
PcbPins
Mold
Frame
SOT-23-5_L2.9-W1.6-H1.1-LS2.8-P0.95
LED_0603_1608Metric
CONN-SMD_P2.00_S2B-PH-SM4-TB-LF-SN
ANT-SMD_4P-L3.2-W1.6-H1.2
Locus-unsaved-export-3NcIAI_PCB

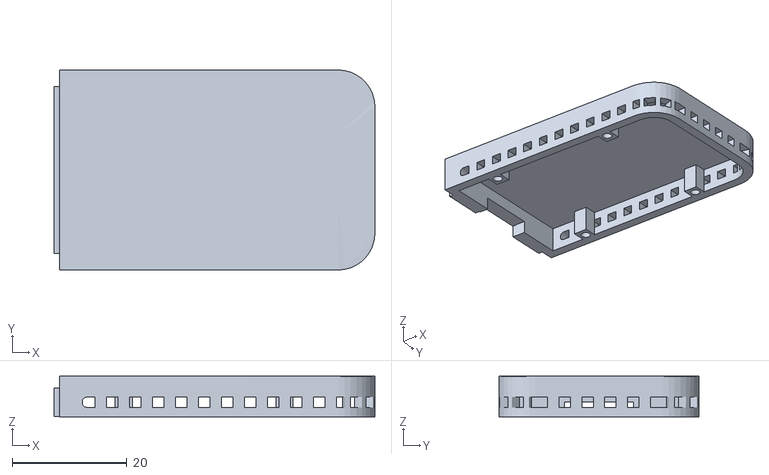
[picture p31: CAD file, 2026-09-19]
3D Models/Versipellis/Veri_Top.stl
55.9 x 34.8 x 7.13

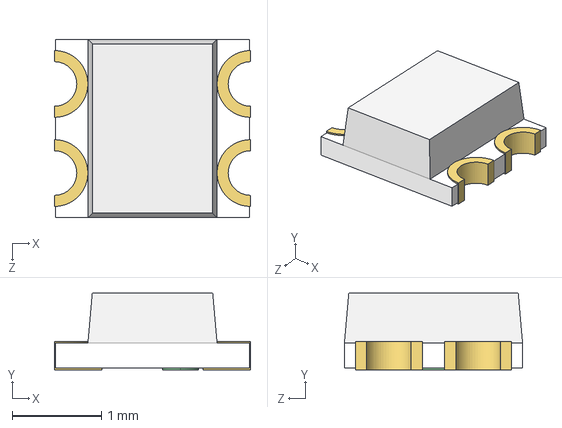
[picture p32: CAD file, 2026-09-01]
KICAD Projects/_Shared/Models/WS2812-2020.STEP
2.20 x 0.86 x 2.00 mm

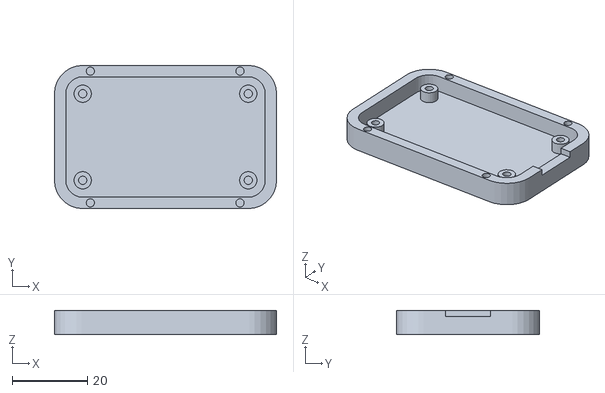
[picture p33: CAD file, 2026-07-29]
3D Models/General/TurrimX1/Turrimlower.stl
59.0 x 38.0 x 6.51

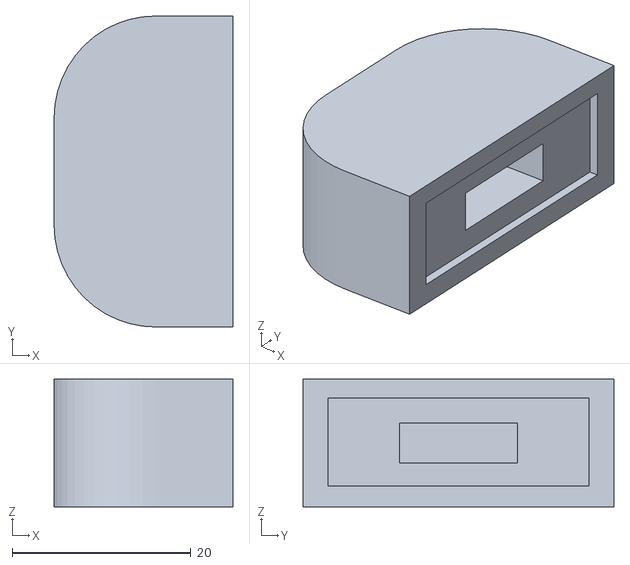
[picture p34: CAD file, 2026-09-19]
3D Models/Versipellis/Veri_Cap.stl
20.0 x 34.8 x 14.3

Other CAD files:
KICAD Projects/_Shared/Models/WLCSP-4(0.8x0.8).step
3D Models/Versipellis/VeriEV1.stl
KICAD Projects/_Shared/Models/USB Connector Type A male, SMT.STEP
KICAD Projects/_Shared/Models/USB-05.stp
3D Models/General/TurrimX1/Turrim.stl
3D Models/Locus/Locus.stl
3D Models/Locus/LocusEV2.stl
3D Models/VeriMini/Primis_VeriMini.stl
3D Models/Versipellis/VeriEV2.stl
KICAD Projects/_Shared/Models/1050570001.stp

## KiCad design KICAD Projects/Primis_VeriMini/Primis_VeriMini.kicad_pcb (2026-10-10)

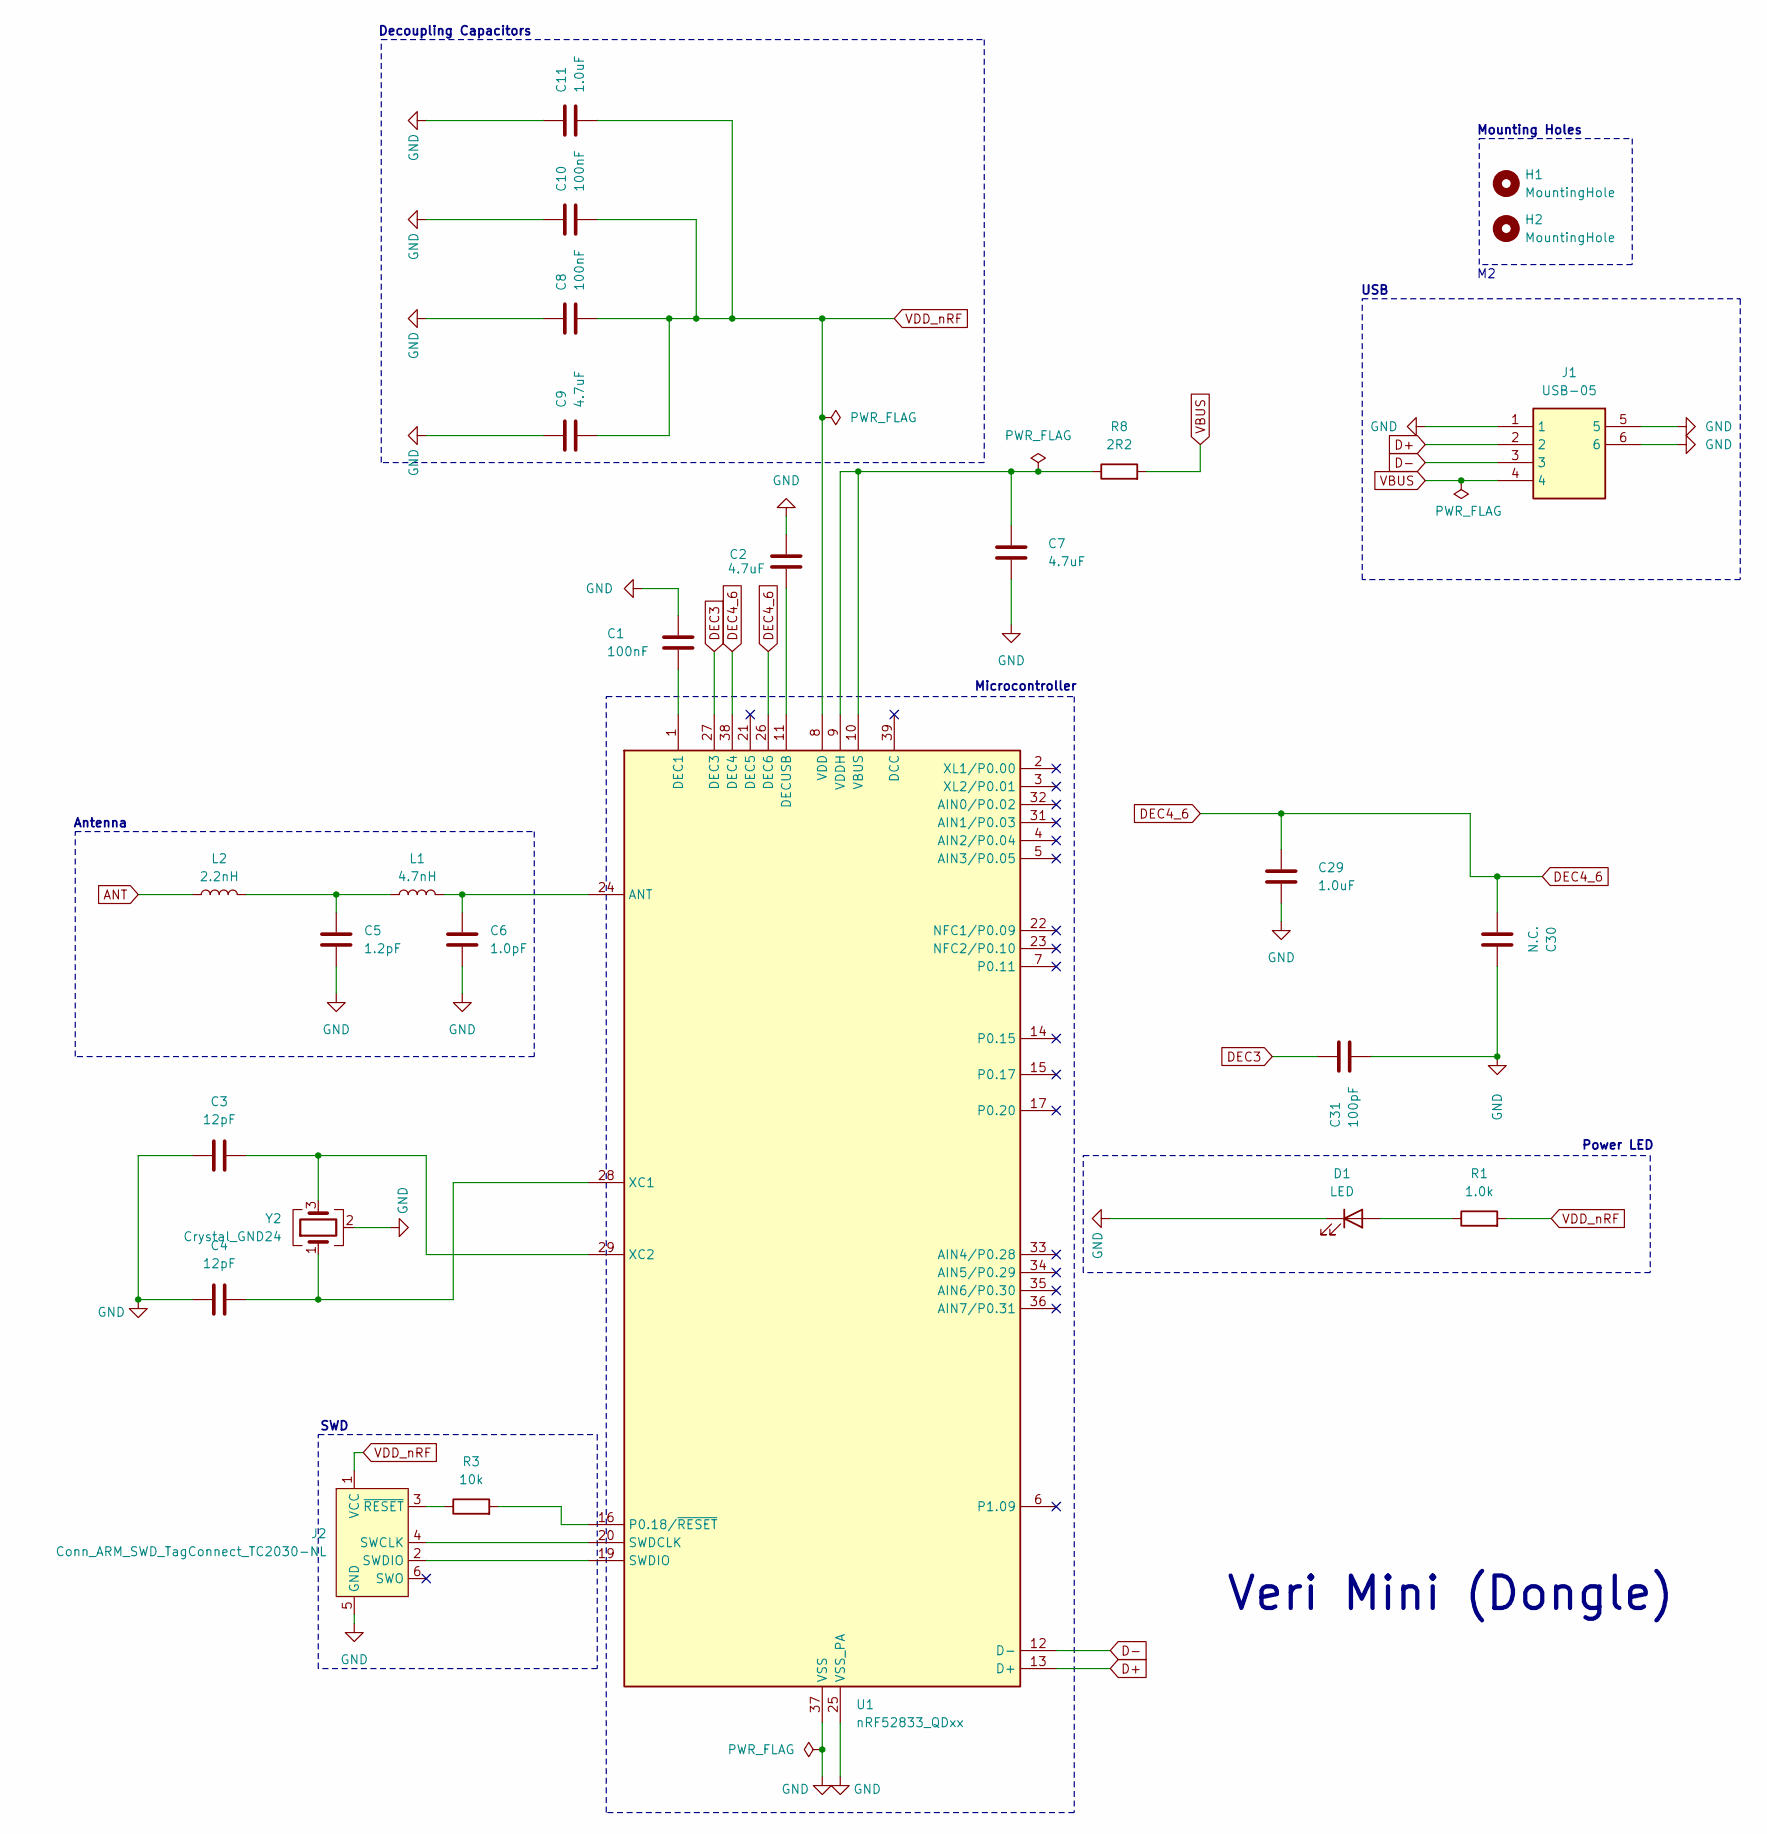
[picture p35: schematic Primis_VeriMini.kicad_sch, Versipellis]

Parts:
C1, C8, C10: 100nF; C_0402_1005Metric
C2, C7, C9: 4.7uF; C_0603_1608Metric
C3, C4: 12pF; C_0402_1005Metric
C5: 1.2pF; C_0402_1005Metric
C6: 1.0pF; C_0402_1005Metric
C11, C29: 1.0uF; C_0402_1005Metric
C30: N.C.; C_0402_1005Metric
C31: 100pF; C_0402_1005Metric
D1: LED; LED_0603_1608Metric
H1, H2: MountingHole; MountingHole_2.2mm_M2
J1: USB-05; USB05; Manufacturer_Part_Number USB-05
J2: Conn_ARM_SWD_TagConnect_TC2030-NL; Tag-Connect_TC2030-IDC-NL_2x03_P1.27mm_Vertical
L1: 4.7nH; L_0402_1005Metric
L2: 2.2nH; L_0402_1005Metric
R1: 1.0k; R_0402_1005Metric
R3: 10k; R_0603_1608Metric
R8: 2R2; R_0603_1608Metric
U1: nRF52833_QDxx; QFN-40-1EP_5x5mm_P0.4mm_EP3.6x3.6mm
Y2: Crystal_GND24; Crystal_SMD_Abracon_ABM8G-4Pin_3.2x2.5mm

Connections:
ANT: L2.1
D+: J1.2, U1.13 (D+)
D-: J1.3, U1.12 (D-)
DEC3: C31.1, U1.27 (DEC3)
DEC4_6: C29.1, C30.2, U1.26 (DEC6), U1.38 (DEC4)
GND: C1.1, C2.2, C3.1, C4.1, C5.1, C6.1, C7.2, C8.1, C9.2, C10.1, C11.2, C29.2, C30.1, C31.2, D1.1 (K), J1.1, J1.5, J1.6, J2.5 (GND), U1.25 (VSS_PA), U1.37 (VSS), U1.41 (VSS), Y2.2 (G), Y2.4 (G)
unnamed: C5.2, L1.1, L2.2
unnamed: D1.2 (A), R1.1
unnamed: J2.4 (SWCLK), U1.20 (SWDCLK)
unnamed: J2.2 (SWDIO), U1.19 (SWDIO)
unnamed: J2.3 (~RESET), R3.1
unnamed: C6.2, L1.2, U1.24 (ANT)
unnamed: C1.2, U1.1 (DEC1)
unnamed: C2.1, U1.11 (DECUSB)
unnamed: R3.2, U1.16 (P0.18/~RESET)
unnamed: C7.1, R8.1, U1.9 (VDDH), U1.10 (VBUS)
unnamed: C4.2, U1.28 (XC1), Y2.1
unnamed: C3.2, U1.29 (XC2), Y2.3
VBUS: J1.4, R8.2
VDD_nRF: C8.2, C9.1, C10.2, C11.1, J2.1 (VCC), R1.2, U1.8 (VDD), U1.18 (VDD), U1.30 (VDD), U1.40 (VDD)

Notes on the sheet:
Mounting Holes
Decoupling Capacitors
Microcontroller
Veri Mini (Dongle)
SWD
Antenna
Power LED
USB

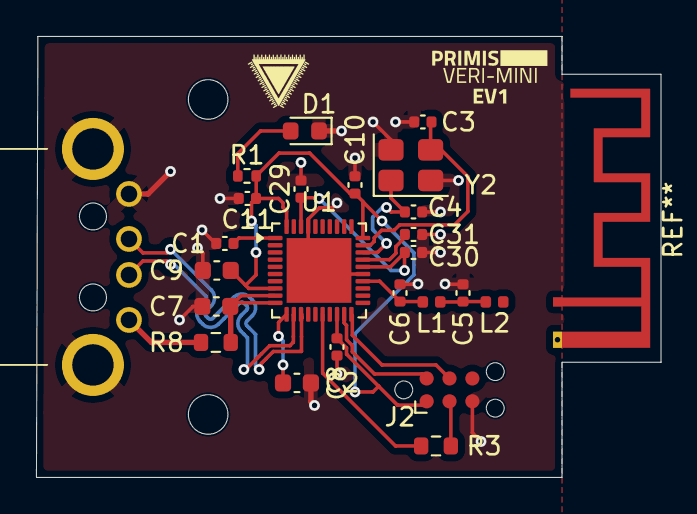
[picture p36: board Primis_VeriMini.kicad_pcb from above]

Board: 2 copper layers, 34.7 x 24.5 mm, 26 parts (0 on the bottom side), 19 nets.

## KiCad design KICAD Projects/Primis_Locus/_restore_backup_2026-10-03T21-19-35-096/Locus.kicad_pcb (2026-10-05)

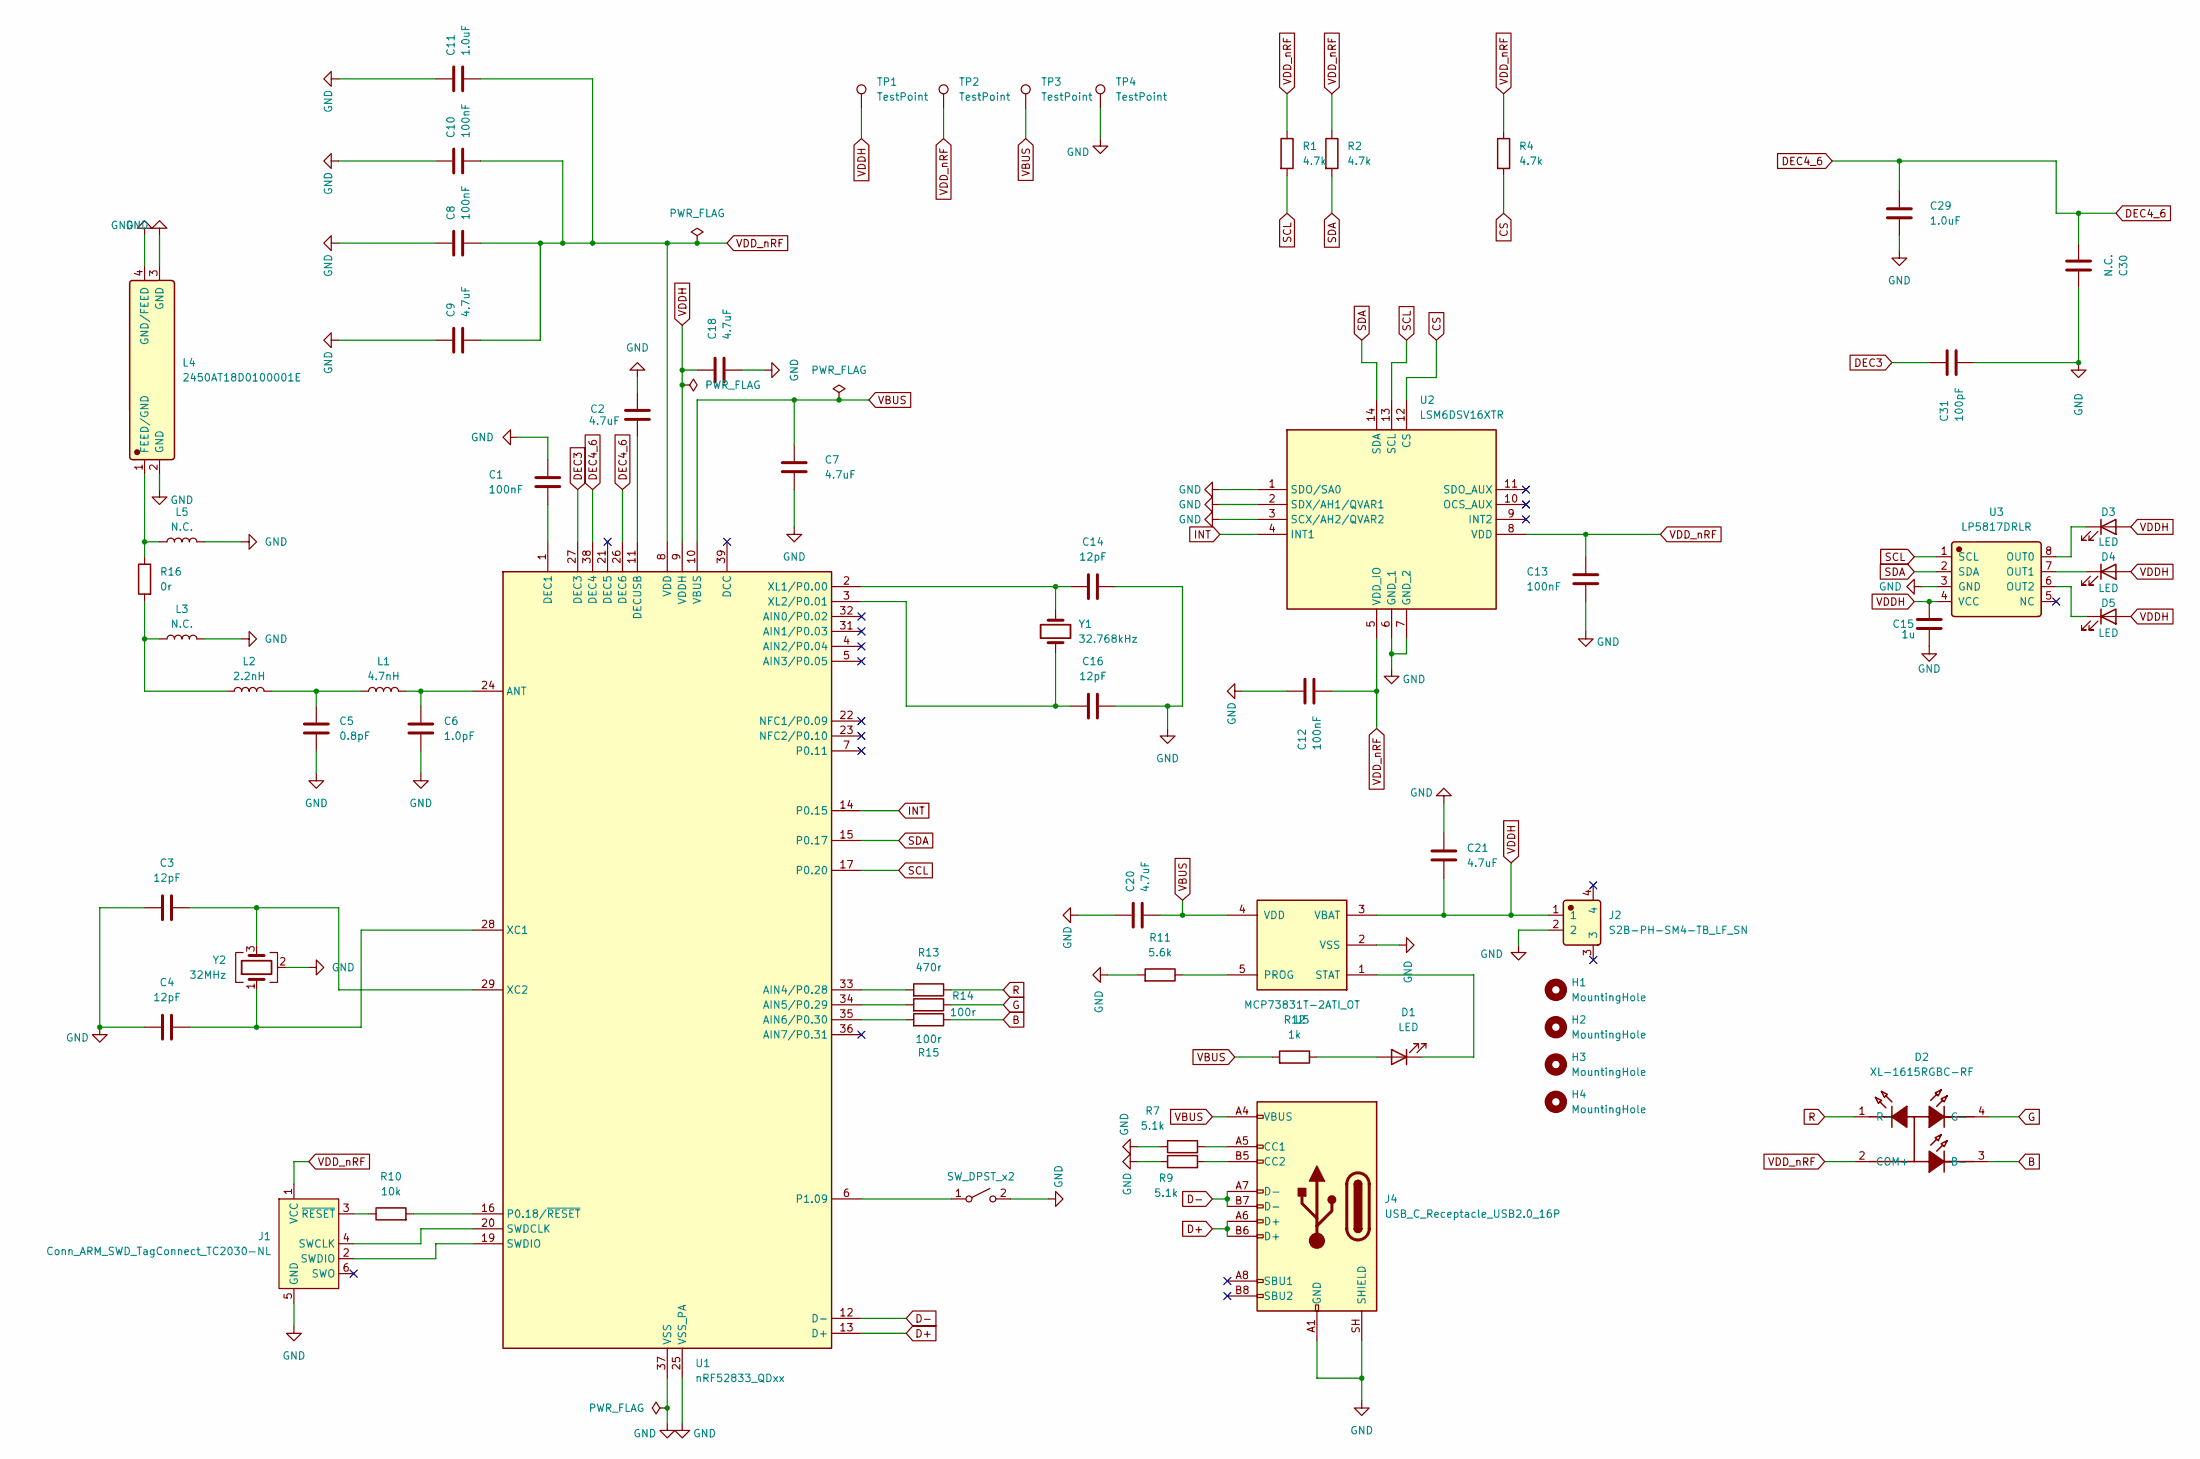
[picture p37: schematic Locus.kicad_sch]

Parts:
C1, C8, C10, C12, C13: 100nF; C_0402_1005Metric
C2, C7, C9, C18, C20, C21: 4.7uF; C_0603_1608Metric
C3, C4, C14, C16: 12pF; C_0402_1005Metric
C5: 0.8pF; C_0402_1005Metric
C6: 1.0pF; C_0402_1005Metric
C11, C29: 1.0uF; C_0402_1005Metric
C15: 1u; C_0402_1005Metric
C30: N.C.; C_0402_1005Metric
C31: 100pF; C_0402_1005Metric
D1: LED; LED_0603_1608Metric
D2: XL-1615RGBC-RF; Manufacturer Part XL-1615RGBC-RF; LCSC C965840
D3, D4, D5: LED; LED_0805_2012Metric
H1, H2, H3, H4: MountingHole; MountingHole_2.7mm_M2.5
J1: Conn_ARM_SWD_TagConnect_TC2030-NL; Tag-Connect_TC2030-IDC-NL_2x03_P1.27mm_Vertical
J2: S2B-PH-SM4-TB_LF_SN; Manufacturer Part S2B-PH-SM4-TB(LF)(SN); LCSC C295747
J4: USB_C_Receptacle_USB2.0_16P; USB_C_Receptacle_HRO_TYPE-C-31-M-12
L1: 4.7nH; L_0402_1005Metric
L2: 2.2nH; L_0402_1005Metric
L3, L5: N.C.; L_0402_1005Metric
L4: 2450AT18D0100001E; Manufacturer Part 2450AT18D0100001E; LCSC C7450310
R1, R2, R4: 4.7k; R_0402_1005Metric
R7, R9: 5.1k; R_0402_1005Metric
R10: 10k; R_0402_1005Metric
R11: 5.6k; R_0402_1005Metric
R12: 1k; R_0402_1005Metric
R13: 470r; R_0402_1005Metric
R14, R15: 100r; R_0402_1005Metric
R16: 0r; R_0402_1005Metric
SW1: SW_DPST_x2; SH-1806SA-A3DW-04
TP1, TP2, TP3, TP4: TestPoint; TestPoint_Pad_1.0x1.0mm
U1: nRF52833_QDxx; QFN-40-1EP_5x5mm_P0.4mm_EP3.6x3.6mm
U2: LSM6DSV16XTR; LSM6DSV16BXTR; Manufacturer_Part_Number LSM6DSV16XTR; Mouser Part Number 511-LSM6DSV16XTR
U3: LP5817DRLR; Manufacturer Part LP5817DRLR; LCSC C47262829
U5: MCP73831T-2ATI_OT; Manufacturer Part MCP73831T-2ATI/OT; LCSC C14879
Y1: 32.768kHz; SC-20S32_768kHz20PPM9pF
Y2: 32MHz; NX2016SA-32MHZ-STD-CZS-5

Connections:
B: D2.3 (B-), R15.1
CS: R4.2, U2.12 (CS)
D+: J4.A6 (D+), J4.B6 (D+), U1.13 (D+)
D-: J4.A7 (D-), J4.B7 (D-), U1.12 (D-)
DEC3: C31.1, U1.27 (DEC3)
DEC4_6: C29.1, C30.2, U1.26 (DEC6), U1.38 (DEC4)
G: D2.4 (G-), R14.1
GND: C1.1, C2.2, C3.1, C4.1, C5.1, C6.1, C7.2, C8.1, C9.2, C10.1, C11.2, C12.1, C13.2, C14.1, C15.2, C16.2, C18.2, C20.2, C21.1, C29.2, C30.1, C31.2, J1.5 (GND), J2.2, J4.A1 (GND), J4.A12 (GND), J4.B1 (GND), J4.B12 (GND), J4.SH (SHIELD), L3.2, L4.2 (GND), L4.3 (GND), L4.4 (GND/FEED), L5.2, R7.1, R9.1, R11.2, SW1.2 (B), TP4.1 (1_1), U1.25 (VSS_PA), U1.37 (VSS), U1.41 (VSS), U2.1 (SDO/SA0), U2.2 (SDX/AH1/QVAR1), U2.3 (SCX/AH2/QVAR2), U2.6 (GND_1), U2.7 (GND_2), U3.3 (GND), U5.2 (VSS), Y2.2 (G), Y2.4 (G)
INT: U1.14 (P0.15), U2.4 (INT1)
unnamed: C5.2, L1.1, L2.2
unnamed: D1.2 (A), R12.1
unnamed: D1.1 (K), U5.1 (STAT)
unnamed: D3.1 (K), U3.8 (OUT0)
unnamed: D4.1 (K), U3.7 (OUT1)
unnamed: D5.1 (K), U3.6 (OUT2)
unnamed: J1.4 (SWCLK), U1.20 (SWDCLK)
unnamed: J1.2 (SWDIO), U1.19 (SWDIO)
unnamed: J1.3 (~RESET), R10.1
unnamed: J4.A5 (CC1), R7.2
unnamed: J4.B5 (CC2), R9.2
unnamed: L2.1, L3.1, R16.2
unnamed: L4.1 (FEED/GND), L5.1, R16.1
unnamed: SW1.1 (A), U1.6 (P1.09)
unnamed: R13.2, U1.33 (AIN4/P0.28)
unnamed: R14.2, U1.34 (AIN5/P0.29)
unnamed: R15.2, U1.35 (AIN6/P0.30)
unnamed: C6.2, L1.2, U1.24 (ANT)
unnamed: C1.2, U1.1 (DEC1)
unnamed: C2.1, U1.11 (DECUSB)
unnamed: R10.2, U1.16 (P0.18/~RESET)
unnamed: C4.2, U1.28 (XC1), Y2.1
unnamed: C3.2, U1.29 (XC2), Y2.3
unnamed: C14.2, U1.2 (XL1/P0.00), Y1.2
unnamed: C16.1, U1.3 (XL2/P0.01), Y1.1
unnamed: R11.1, U5.5 (PROG)
R: D2.1 (R-), R13.1
SCL: R1.2, U1.17 (P0.20), U2.13 (SCL), U3.1 (SCL)
SDA: R2.2, U1.15 (P0.17), U2.14 (SDA), U3.2 (SDA)
VBUS: C7.1, C20.1, J4.A4 (VBUS), J4.A9 (VBUS), J4.B4 (VBUS), J4.B9 (VBUS), R12.2, TP3.1 (1_1), U1.10 (VBUS), U5.4 (VDD)
VDDH: C15.1, C18.1, C21.2, D3.2 (A), D4.2 (A), D5.2 (A), J2.1, TP1.1 (1_1), U1.9 (VDDH), U3.4 (VCC), U5.3 (VBAT)
VDD_nRF: C8.2, C9.1, C10.2, C11.1, C12.2, C13.1, D2.2 (COM+), J1.1 (VCC), R1.1, R2.1, R4.1, TP2.1 (1_1), U1.8 (VDD), U1.18 (VDD), U1.30 (VDD), U1.40 (VDD), U2.5 (VDD_IO), U2.8 (VDD)

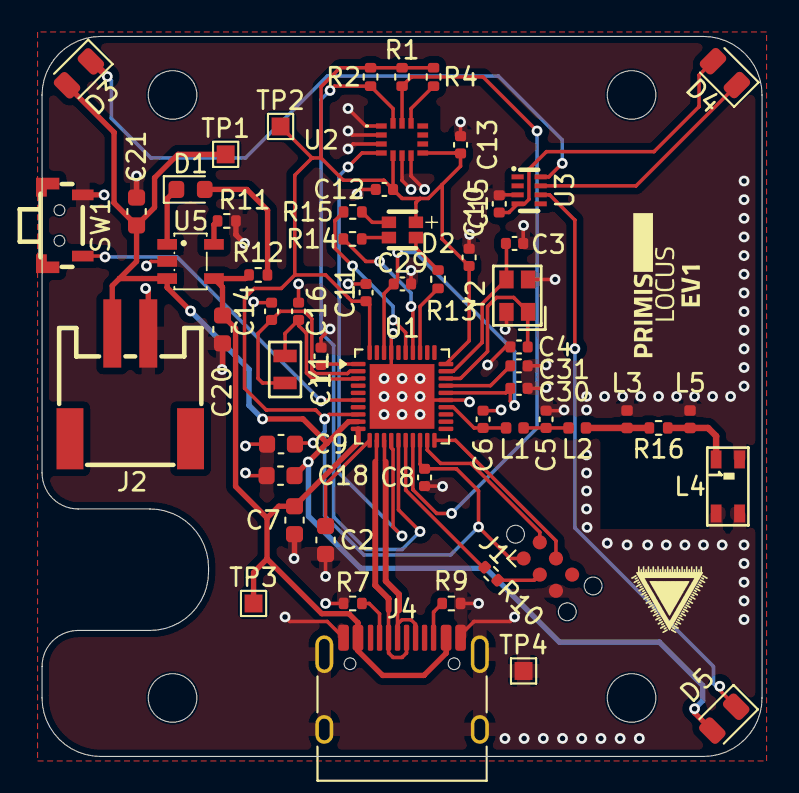
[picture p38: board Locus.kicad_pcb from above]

Board: 4 copper layers, 40.0 x 40.0 mm, 62 parts (0 on the bottom side), 41 nets.

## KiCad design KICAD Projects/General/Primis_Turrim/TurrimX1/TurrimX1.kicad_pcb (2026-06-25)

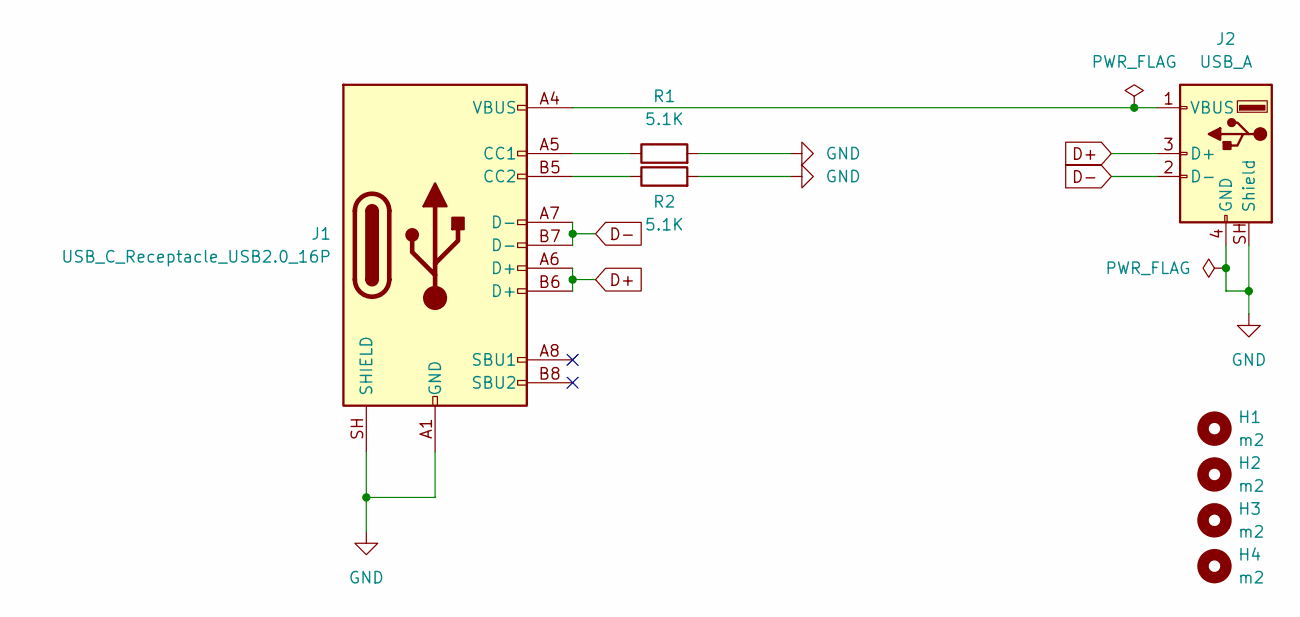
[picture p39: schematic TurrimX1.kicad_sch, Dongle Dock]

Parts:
H1, H2, H3, H4: m2; MountingHole_2.2mm_M2
J1: USB_C_Receptacle_USB2.0_16P; USB_C_Receptacle_HRO_TYPE-C-31-M-12
J2: USB_A; USB_A_Molex_105057_Vertical
R1, R2: 5.1K; R_0805_2012Metric

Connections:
D+: J1.A6 (D+), J1.B6 (D+), J2.3 (D+)
D-: J1.A7 (D-), J1.B7 (D-), J2.2 (D-)
GND: J1.A1 (GND), J1.A12 (GND), J1.B1 (GND), J1.B12 (GND), J1.SH (SHIELD), J2.4 (GND), J2.SH (Shield), R1.2, R2.2
unnamed: J1.A5 (CC1), R1.1
unnamed: J1.B5 (CC2), R2.1
unnamed: J1.A4 (VBUS), J1.A9 (VBUS), J1.B4 (VBUS), J1.B9 (VBUS), J2.1 (VBUS)

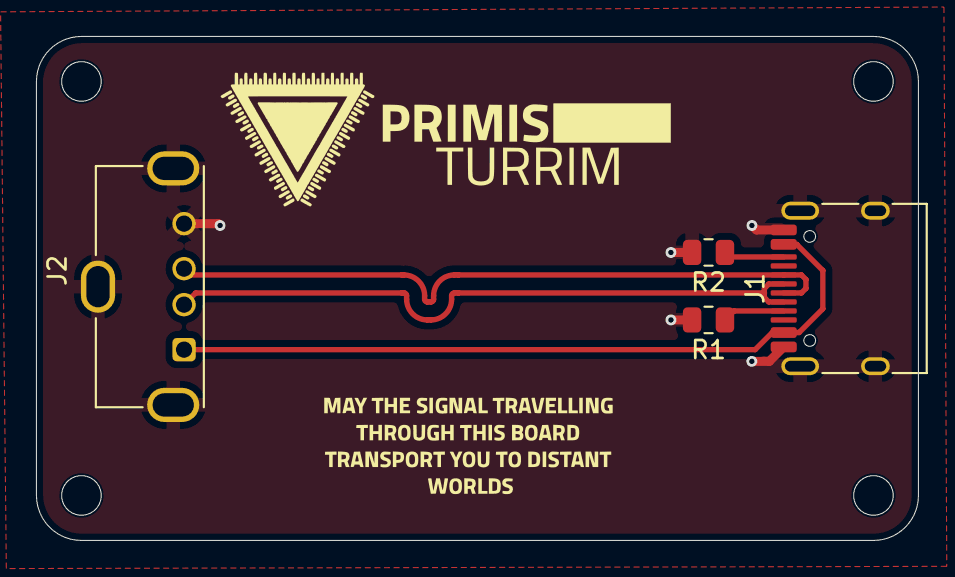
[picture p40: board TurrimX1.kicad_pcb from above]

Board: 2 copper layers, 49.0 x 28.0 mm, 8 parts (0 on the bottom side), 6 nets.

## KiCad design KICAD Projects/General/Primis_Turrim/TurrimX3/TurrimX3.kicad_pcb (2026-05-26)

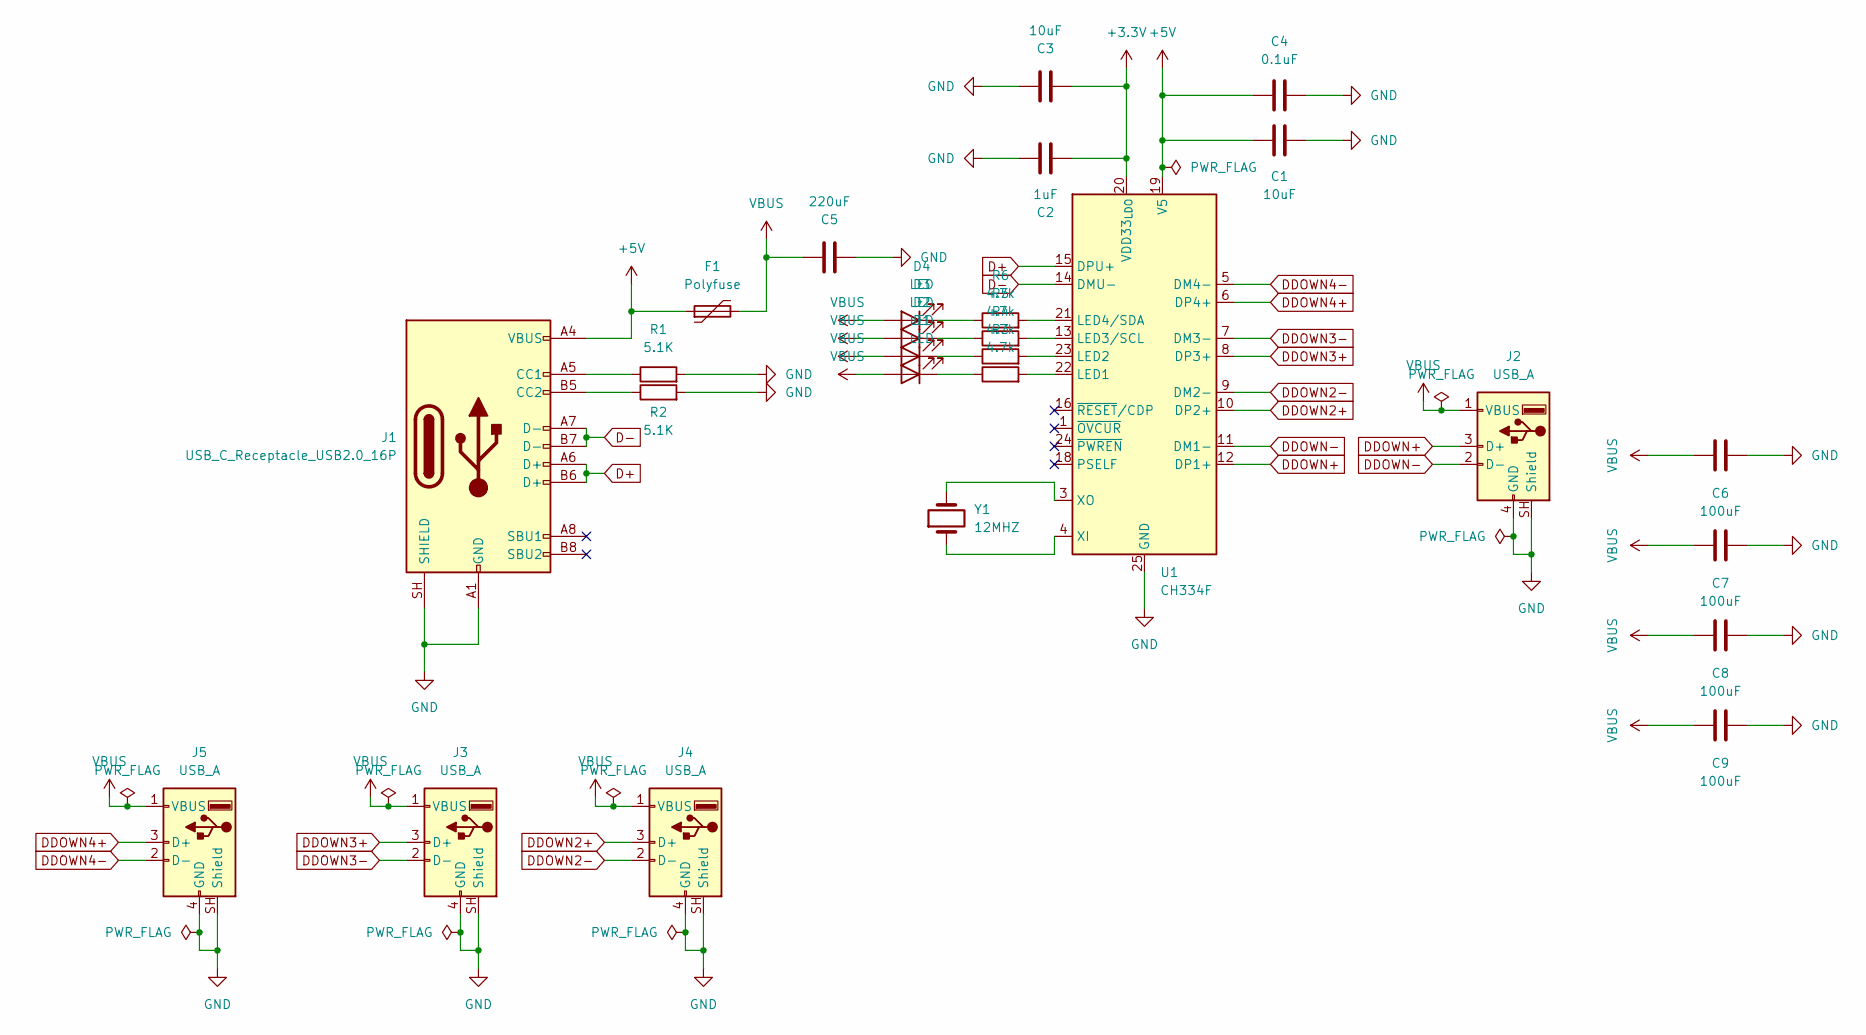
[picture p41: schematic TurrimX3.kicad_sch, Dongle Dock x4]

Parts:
C1, C3: 10uF; C_0805_2012Metric
C2: 1uF; C_0603_1608Metric
C4: 0.1uF; C_0603_1608Metric
C5: 220uF; C_0805_2012Metric
C6, C7, C8, C9: 100uF; C_0805_2012Metric
D1, D2, D3, D4: LED; LED_0603_1608Metric
F1: Polyfuse; Fuse_1206_3216Metric
J1: USB_C_Receptacle_USB2.0_16P; USB_C_Receptacle_HRO_TYPE-C-31-M-12
J2, J3, J4, J5: USB_A; USB_A_Molex_105057_Vertical
R1, R2: 5.1K; R_0805_2012Metric
R3, R4, R5, R6: 4.7k; R_0805_2012Metric
U1: CH334F; QFN-24-1EP_4x4mm_P0.5mm_EP2.7x2.7mm
Y1: 12MHZ; Crystal_SMD_2016-4Pin_2.0x1.6mm

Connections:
+3.3V: C2.1, C3.1, U1.20 (VDD33_{LDO})
+5V: C1.1, C4.1, F1.1, J1.A4 (VBUS), J1.A9 (VBUS), J1.B4 (VBUS), J1.B9 (VBUS), U1.19 (V5)
D+: J1.A6 (D+), J1.B6 (D+), U1.15 (DPU+)
D-: J1.A7 (D-), J1.B7 (D-), U1.14 (DMU-)
DDOWN2+: J4.3 (D+), U1.10 (DP2+)
DDOWN2-: J4.2 (D-), U1.9 (DM2-)
DDOWN3+: J3.3 (D+), U1.8 (DP3+)
DDOWN3-: J3.2 (D-), U1.7 (DM3-)
DDOWN4+: J5.3 (D+), U1.6 (DP4+)
DDOWN4-: J5.2 (D-), U1.5 (DM4-)
DDOWN+: J2.3 (D+), U1.12 (DP1+)
DDOWN-: J2.2 (D-), U1.11 (DM1-)
GND: C1.2, C2.2, C3.2, C4.2, C5.1, C6.2, C7.2, C8.2, C9.2, J1.A1 (GND), J1.A12 (GND), J1.B1 (GND), J1.B12 (GND), J1.SH (SHIELD), J2.4 (GND), J2.SH (Shield), J3.4 (GND), J3.SH (Shield), J4.4 (GND), J4.SH (Shield), J5.4 (GND), J5.SH (Shield), R1.2, R2.2, U1.25 (GND)
unnamed: D1.1 (K), R3.1
unnamed: D2.1 (K), R4.1
unnamed: D3.1 (K), R5.1
unnamed: D4.1 (K), R6.1
unnamed: J1.A5 (CC1), R1.1
unnamed: J1.B5 (CC2), R2.1
unnamed: R3.2, U1.22 (LED1)
unnamed: R4.2, U1.23 (LED2)
unnamed: R5.2, U1.13 (LED3/SCL)
unnamed: R6.2, U1.21 (LED4/SDA)
unnamed: U1.4 (XI), Y1.1
unnamed: U1.3 (XO), Y1.2
VBUS: C5.2, C6.1, C7.1, C8.1, C9.1, D1.2 (A), D2.2 (A), D3.2 (A), D4.2 (A), F1.2, J2.1 (VBUS), J3.1 (VBUS), J4.1 (VBUS), J5.1 (VBUS)

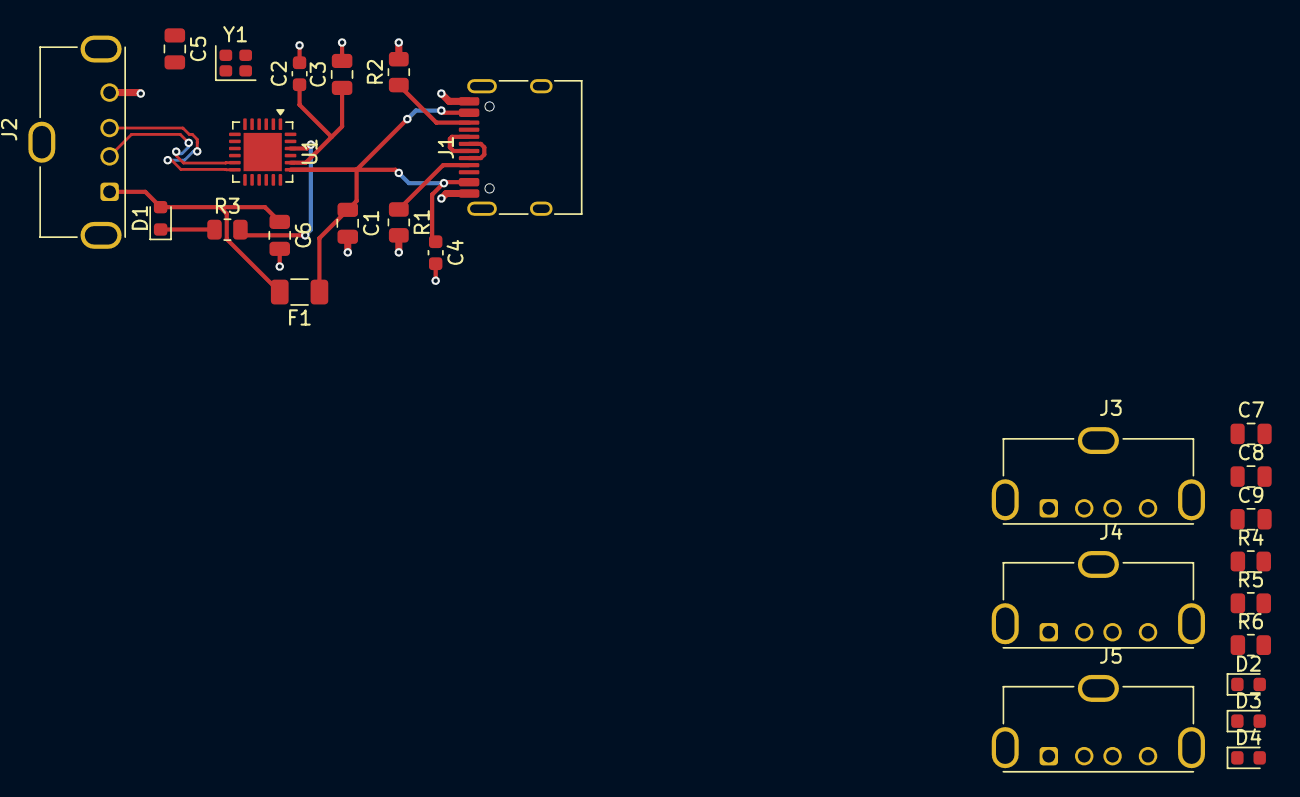
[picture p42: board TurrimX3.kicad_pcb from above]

Board: 2 copper layers, 27 parts (0 on the bottom side), 26 nets.

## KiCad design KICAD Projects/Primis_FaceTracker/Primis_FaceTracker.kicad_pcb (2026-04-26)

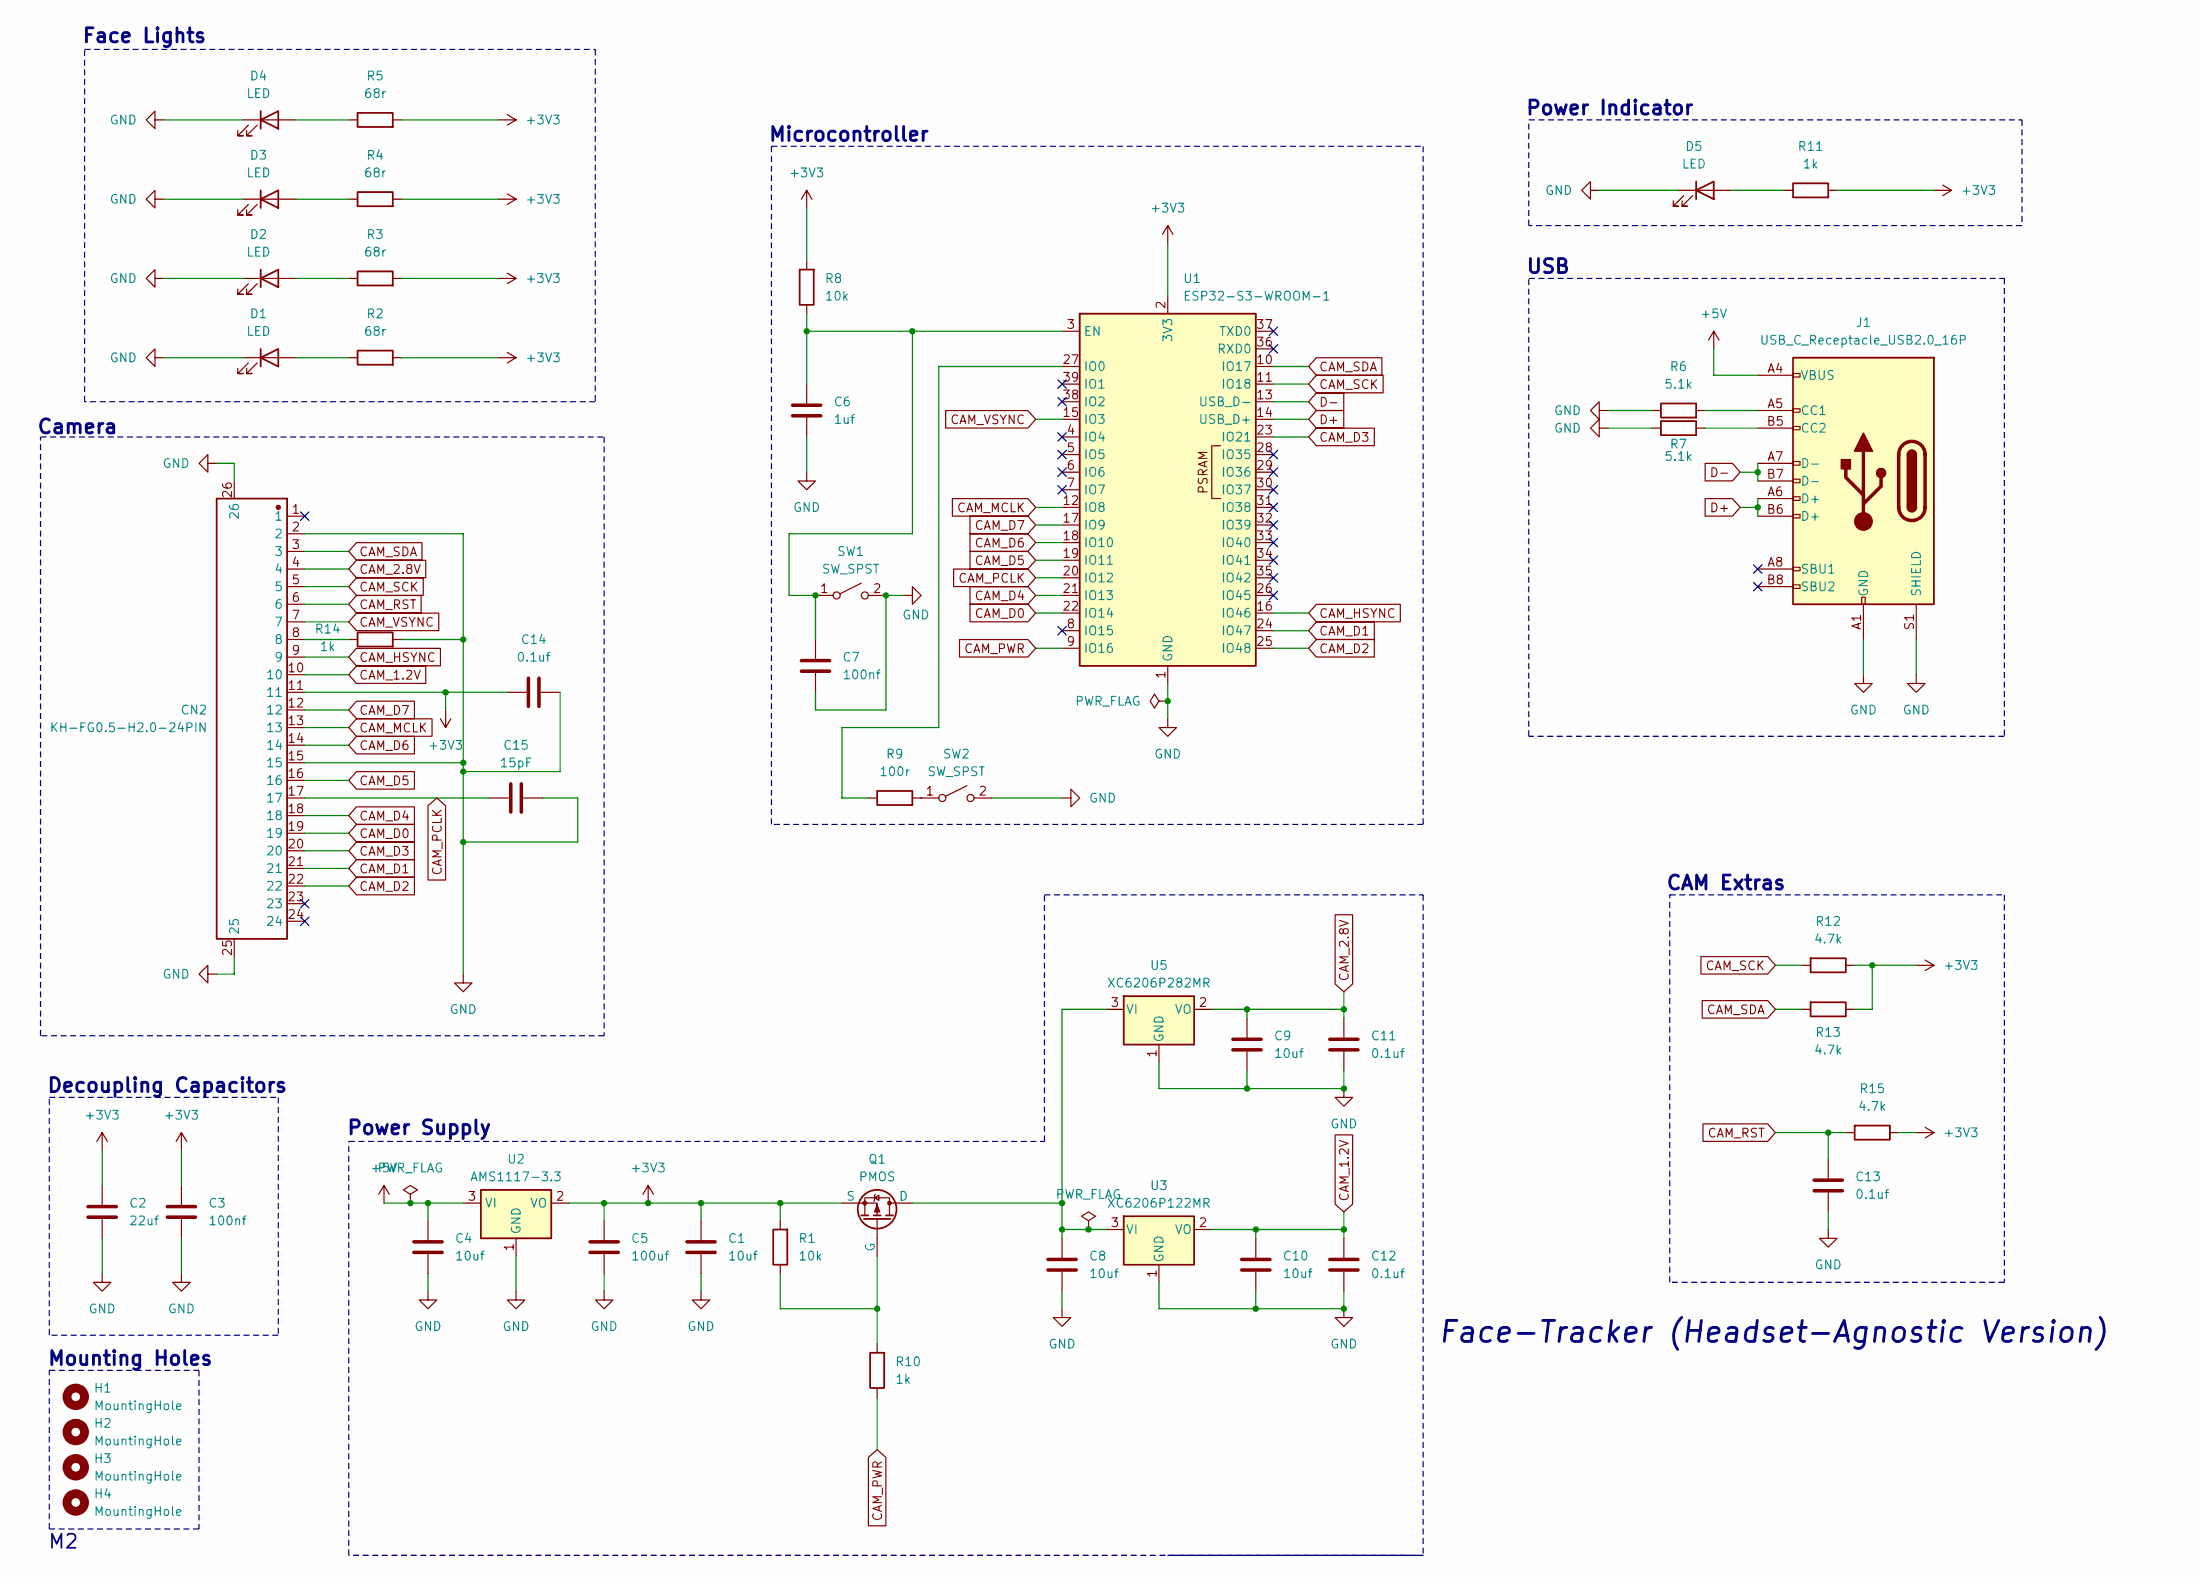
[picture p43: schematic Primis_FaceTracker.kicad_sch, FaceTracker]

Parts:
C1, C4, C8, C9, C10: 10uf; C_0805_2012Metric
C2: 22uf; C_0805_2012Metric
C3, C7: 100nf; C_0603_1608Metric
C5: 100uf; C_1206_3216Metric
C6: 1uf; C_0603_1608Metric
C11, C12, C13, C14: 0.1uf; C_0603_1608Metric
C15: 15pF; C_0603_1608Metric
CN2: KH-FG0.5-H2.0-24PIN; FPC-SMD_KH-FG0.5-H2.0-24PIN
D1, D2, D3, D4, D5: LED; LED_0805_2012Metric
H1, H2, H3, H4: MountingHole; MountingHole_2.2mm_M2
J1: USB_C_Receptacle_USB2.0_16P; USB_C_Receptacle_HRO_TYPE-C-31-M-12
Q1: PMOS; SOT-23
R1, R8: 10k; R_0805_2012Metric
R2, R3, R4, R5: 68r; R_0603_1608Metric
R6, R7: 5.1k; R_0805_2012Metric
R9: 100r; R_0603_1608Metric
R10, R11, R14: 1k; R_0805_2012Metric
R12, R13, R15: 4.7k; R_0805_2012Metric
SW1, SW2: SW_SPST; SW_SPST_TS-1088-xR020
U1: ESP32-S3-WROOM-1
U2: AMS1117-3.3; SOT-223-3_TabPin2
U3: XC6206P122MR; SOT-23-3
U5: XC6206P282MR; SOT-23-3

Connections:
+3V3: C1.1, C2.1, C3.1, C5.1, C14.1, CN2.11, Q1.3 (S), R1.2, R2.2, R3.2, R4.2, R5.2, R8.2, R11.2, R12.1, R13.1, R15.1, U1.2 (3V3), U2.2 (VO)
+5V: C4.1, J1.A4 (VBUS), J1.A9 (VBUS), J1.B4 (VBUS), J1.B9 (VBUS), U2.3 (VI)
CAM_1.2V: C10.1, C12.1, CN2.10, U3.2 (VO)
CAM_2.8V: C9.1, C11.1, CN2.4, U5.2 (VO)
CAM_D0: CN2.19, U1.22 (IO14)
CAM_D1: CN2.21, U1.24 (IO47)
CAM_D2: CN2.22, U1.25 (IO48)
CAM_D3: CN2.20, U1.23 (IO21)
CAM_D4: CN2.18, U1.21 (IO13)
CAM_D5: CN2.16, U1.19 (IO11)
CAM_D6: CN2.14, U1.18 (IO10)
CAM_D7: CN2.12, U1.17 (IO9)
CAM_HSYNC: CN2.9, U1.16 (IO46)
CAM_MCLK: CN2.13, U1.12 (IO8)
CAM_PCLK: C15.1, CN2.17, U1.20 (IO12)
CAM_PWR: R10.1, U1.9 (IO16)
CAM_RST: C13.1, CN2.6, R15.2
CAM_SCK: CN2.5, R12.2, U1.11 (IO18)
CAM_SDA: CN2.3, R13.2, U1.10 (IO17)
CAM_VSYNC: CN2.7, U1.15 (IO3)
D+: J1.A6 (D+), J1.B6 (D+), U1.14 (USB_D+)
D-: J1.A7 (D-), J1.B7 (D-), U1.13 (USB_D-)
GND: C1.2, C2.2, C3.2, C4.2, C5.2, C6.2, C7.1, C8.2, C9.2, C10.2, C11.2, C12.2, C13.2, C14.2, C15.2, CN2.2, CN2.15, CN2.25, CN2.26, D1.1 (K), D2.1 (K), D3.1 (K), D4.1 (K), D5.1 (K), J1.A1 (GND), J1.A12 (GND), J1.B1 (GND), J1.B12 (GND), J1.S1 (SHIELD), R6.1, R7.1, R14.2, SW1.2 (B), SW2.2 (B), U1.1 (GND), U1.40 (GND), U1.41 (GND), U2.1 (GND), U3.1 (GND), U5.1 (GND)
unnamed: CN2.8, R14.1
unnamed: D1.2 (A), R2.1
unnamed: D2.2 (A), R3.1
unnamed: D3.2 (A), R4.1
unnamed: D4.2 (A), R5.1
unnamed: D5.2 (A), R11.1
unnamed: J1.A5 (CC1), R6.2
unnamed: J1.B5 (CC2), R7.2
unnamed: C8.1, Q1.1 (D), U3.3 (VI), U5.3 (VI)
unnamed: Q1.2 (G), R1.1, R10.2
unnamed: C6.1, C7.2, R8.1, SW1.1 (A), U1.3 (EN)
unnamed: R9.2, SW2.1 (A)
unnamed: R9.1, U1.27 (IO0)

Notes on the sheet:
Decoupling Capacitors
Face Lights
Mounting Holes
Microcontroller
Power Indicator
Face-Tracker (Headset-Agnostic Version)
USB
Camera
CAM Extras
Power Supply

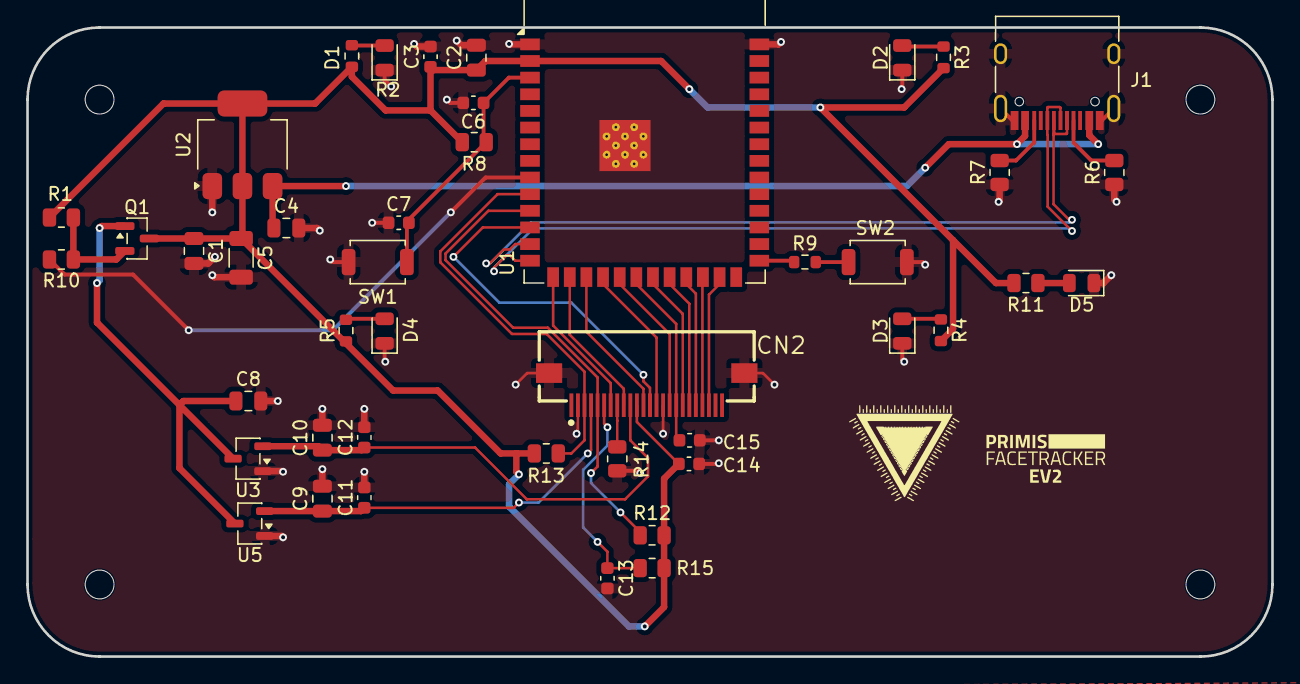
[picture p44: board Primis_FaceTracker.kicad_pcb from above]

Board: 2 copper layers, 95.0 x 48.0 mm, 48 parts (0 on the bottom side), 36 nets.

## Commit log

2026-02-11 Face Tracker and Versipellis Clean
    -Organised the face tracker PCB a bit more
    -Added TODO to face tracker README
    -Organised Versipellis schematics
    -Updated images
    [Primis_FaceTracker.kicad_pcb, Primis_Versipellis.kicad_sch]
2026-02-17 Gerbers plus clean up
    -Added gerbers for the face tracker and versipellis
    -Shrunk the face tracker and cleaned up
    -Fixed some DRC issues with both projects
    [Primis_FaceTracker-B_Cu.gbr, Primis_FaceTracker-B_Mask.gbr, Primis_FaceTracker-B_Paste.gbr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]
2026-03-10 Quick Update
    [Primis_FaceTracker-B_Cu.gbr, Primis_FaceTracker-B_Mask.gbr, Primis_FaceTracker-B_Paste.gbr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]
2026-04-26 FaceTracker fixes and Dongle rework
    -Fixed some mistakes on the Facetracker with the camera power lines.
    -Some part swaps and additions on the dongle to match the JLCPCBs catalogue
    [Primis_FaceTracker.kicad_pcb, Primis_FaceTracker.kicad_sch, Primis_Versipellis.kicad_pcb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]
2026-04-27 Usb swap
    -Changed the dongle to another usb
    [Primis_Versipellis.kicad_pcb, Primis_Versipellis.kicad_sch]
2026-05-02 Dongle Cleanup
    -CLeanup before final
    [Primis_Versipellis.kicad_pcb]
2026-05-02 Versipellis EV1 Final + General Github updates
    -Fixed a few remaining issues with Versipellis EV1
    -Created production files for Versipellis
    -Updated pictures for all projects
    [BOM-Primis_Versipellis.csv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]
2026-05-13 Quick EV1 Dongle Fixes
    -Made some last minute fixes
    [BOM-Primis_Versipellis.csv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]
2026-05-19 Organised + Added Turrim and Model
    -Added folder structure for all files types
    -Added general folder for small supplementary projects
    -Added Turrim (Dongle hub for Frame dongles)
    -Added PCB model for the Frame dongles
    [Turrim.kicad_pcb, Turrim.kicad_sch, Veri.stl]
2026-05-26 Big Update
    -Added Versipellis pictures
    -Split Turrim into 2 versions, a simple, cheap 1 port version and a more complex 4 port hub version.
    -Started work on Locus
    [1050570001.stp, BOM-TurrimX1.csv, Turrim.kicad_pcb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]
2026-06-25 VERSIPELLIS EV2 + TURRIM Production files
    -Swapped to a tag connect for programming VERSIPELLIS
    -Moved crystal closer to the NRF on VERSIPELLIS
    -Fixed swapped lines on usb on VERSIPELLIS
    -TURRIM cleanup and production files added
    [BOM-Primis_Versipellis.csv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]
2026-06-29 VERSIPELLIS/TURRIM Model files
    -Added VERSIPELLIS EV2 model
    -Added TURRIM model
    -Added VERSIPELLIS case models
    -Update images
    [Turrim.stl, VeriCap_fixed.stl, VeriEV1.stl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]
2026-07-03 Locus Progress
    -Finished Locus schematics
    -Started on Locus PCB layout
    [Locus.kicad_pcb, Locus.kicad_sch]
2026-07-29 More Locus work
    -Just a quick backup of newest work on Locus
    [Locus.kicad_pcb, Locus.kicad_sch, Turrimlower.stl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]
2026-09-01 Locus redesign + Some Models
    -Locus now uses some 0402 parts
    -Removed a bunch of unnecessary parts from Locus
    -Shrunk the design down as a result
    -Nearly finished routing Locus
    [FaceTrackerA.step, Frame_FaceTracker.kicad_pcb, Frame_FaceTracker.kicad_sch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]
2026-09-03 Locus EV1 Final
    -Finished Locus EV1
    [Locus.kicad_pcb, Locus.kicad_sch]
2026-09-03 Locus EV1 quick fixes
    [Locus.kicad_pcb, Locus.kicad_sch]
2026-09-03 Locus EV11 Production fix
    For real this time
    [bom.csv, designators.csv, positions.csv]
2026-09-03 Locus EV1 Crystal Fix
    -One last crystal fixed, there good for real this time ordered
    [Locus.kicad_pcb, Locus.kicad_sch, bom.csv]
2026-09-19 CleanUp
    -Added Locus EV1 STEP and STL files
    -Added Locus PCB picture
    -Added very early work on PI3 carrier board
    -Added nearly complete VeriMini kicad project
    -Added extra details to README
    [BOM-Primis_Versipellis.csv, Locus.step, Locus.stl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]
2026-10-03 Issues + README cleanup
    -Added current issues to each device in each device readme
2026-10-04 ev2 wip1
    [Locus.kicad_pcb, Locus.kicad_sch]
2026-10-05 Added Revision History
    [Locus.kicad_pcb, Locus.kicad_sch, bom.csv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]
2026-10-05 ev2 pr
    [Locus.kicad_pcb, Locus.kicad_sch]
2026-10-05 Fixed LocusEV2 rev number
    [Locus.kicad_pcb]
2026-10-09 Offical Frame CAD and more release
    -Add a link to Valves Steam Frame repo
    -Further iteration on Veri Mini
    [Primis_VeriMini.kicad_pcb, Primis_VeriMini.kicad_sch]
2026-10-10 VeriMini EV1 + Locus EV2 models and production files
    -VeriMini EV1 is now functionally complete, going to most likely do some more small clean up work
    -Added Locus EV2 and VeriMini EV1 steps and stl files
    -Added pictures and production files for both VeriMini EV1 and Locus EV2
    [LocusEV2.step, LocusEV2.stl, Primis_VeriMini.kicad_pcb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]
